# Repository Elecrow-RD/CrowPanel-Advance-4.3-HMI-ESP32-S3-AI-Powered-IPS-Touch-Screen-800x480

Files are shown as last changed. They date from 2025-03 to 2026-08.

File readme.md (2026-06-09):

## Menu
### 1, Product picture
### 2, Product version number
### 3, product information
### 4, Use the driver module
### 5,Quick Start
### 6,Folder structure.
### 7,Pin definition
### 8,Guidelines for downloading some of the files from the github repository

### 1, Product picture

Crowpanel Advance 4.3 HMI display support Meshtastic

### 2, Product version number

| | Hardware | Software | Remark |
| ---- | --- | --- | --- |
| 1 | V1.0 | V1.0 | old |
| 2 | V1.1 | V1.1 | old |
| 3 | V1.2 | V1.2 | old |
| 4 | V1.3 | V1.2 | latest |

### Version update points:
① Version 1.1 updated the control of backlight on the basis of the original, the backlight of version 1.2 is controlled by STC8H1K28 microcontroller, and the backlight is lit in the program by sending the value to this microcontroller address (0x30). The values are 0-245, where 245 switches off the backlight and 0 is the maximum brightness.

② Version 1.1 has a new option for function switching, see above for details. When using the case, please select the corresponding program to test or modify according to the version number of your motherboard.

## Version 1.2
Only the button component has been updated. All other hardware and I/O pins remain the same as in the previous version.

## Version 1.3
Version 1.3 is simply an update to the previous version that modifies the packaging of the touchscreen FPC connector. There are no other differences.

### 3, product information

| Main Chip-ESP32-S3-WROOM-1-N16R8 | |
| --- | --- |
| CPU/SoC | high-performance Xtensa 32-bit LX7 dual-core processor, with up to 240MHz |
| System Memory | 512KB SRAM、8M PSRAM |
| Memory | 16M Flash，384KB ROM |
| Development Language | MicroPython、C/C++ |
| Development Environment | ESP-IDF、Arduino IDE、PlatformIO、MicroPython |
| **Screen** | |
| Size | 4.3 inch |
| Diver IC | ST7265 |
| Resolution | 800*480 |
| Display Panel | IPS Panel |
| Touch Panel | Capacitive Single Touch |
| Viewing Angle | 178° |
| Brightness | 400 cd/m²(Typ.) |
| Color Depth | 16-bit |
| **Wireless Communication - Onboard Antenna** | |
| WiFi | Support 2.4GHz, 802.11a/b/g/n |
| Bluetooth | Support Bluetooth 5.0 and BLE |
| Other | **LoRa** |
| **Interface/Function** | |
| Interface | USB port, UART, I2C, SD card slot, battery socket, speaker port, microphone, etc. |
| Function | RTC clock, audio amplifier, volume control, battery charge management, USB to UART, etc. |
| **Button/LED Indicator** | |
| Reset Button | Yes, press to reset the device |
| Boot Button | Yes, press and hold the power button to burn the program |
| PWR | Power indicator |
| CHG | Lithium battery charging status, completion indication |
| **Other** | |
| Installation method | Back hanging, fixed hole |
| Operating temperature | -20~70 °C |
| Storage temperature | -30~80 °C |
| Power Input | 5V/2A, USB or UART terminal |
| Active Area | 95.5mm*54mm |
| Dimensions | 121.9*75.6*15.3mm |

### 4, Use the driver module

| Name | dependency library |
| --- | --- |
| LVGL | lvgl/lvgl@8.3.3 |
| ST7789 | Adafruit GFX Library<br/>version=1.11.0 |

### 5,Quick Start
### Arduino IDE starts

#### Teaching Case Path：./example/example_code4.3

1.Download the library files used by this product to the 'libraries' folder.

C:\Users\Documents\Arduino\libraries\



2.Open the Arduino IDE



3.Open the code configuration environment and burn it



### ESP-IDF starts

#### Teaching Case Path：./example/idf_code

1.Right-click on an empty space in the project folder and select "Open with VS Code" to open the project.


2.In the IDF plug-in, select the port, then compile and flash


### 6,Folder structure.
|--3D file： Contains 3D model files (.stp) for the hardware. These files can be used for visualization, enclosure design, or integration into CAD software.

|--Datasheet: Includes datasheets for components used in the project, providing detailed specifications, electrical characteristics, and pin configurations.

|--Eagle_SCH&PCB: Contains Eagle CAD schematic (.sch) and PCB layout (.brd) files. These are used for circuit design and PCB manufacturing.

|--example: Provides example code and projects to demonstrate how to use the hardware and libraries. These examples help users get started quickly.

|--factory_firmware: Stores pre-compiled factory firmware that can be directly flashed onto the device. This ensures the device runs the default functionality.

|--factory_sourcecode: Contains the source code for the factory firmware, allowing users to modify and rebuild the firmware as needed.

|--libraries: Includes necessary libraries required for compiling and running the project. These libraries provide drivers and additional functionalities for the hardware.

|--Squareline_studio Instructions for use: Squareline_studio instructions: Demonstrate the use of squareline studio.

### 7,Pin definition

#define HSPI_MISO  4

#define HSPI_MOSI  6

#define HSPI_SCLK  5

#define HSPI_SS    19

#define SD_MOSI 6

#define SD_MISO 4

#define SD_SCK 5

#define SD_CS 0 //The chip selector pin is not connected to IO

#define I2S_DOUT 4

#define I2S_BCLK 5

#define I2S_LRC 6

      cfg.pin_d0 = GPIO_NUM_21;    // B0

      cfg.pin_d1 = GPIO_NUM_47;    // B1

      cfg.pin_d2 = GPIO_NUM_48;   // B2

      cfg.pin_d3 = GPIO_NUM_45;    // B3

      cfg.pin_d4 = GPIO_NUM_38;    // B4

      cfg.pin_d5 = GPIO_NUM_9;    // G0

      cfg.pin_d6 = GPIO_NUM_10;    // G1

      cfg.pin_d7 = GPIO_NUM_11;    // G2

      cfg.pin_d8 = GPIO_NUM_12;   // G3

      cfg.pin_d9 = GPIO_NUM_13;   // G4

      cfg.pin_d10 = GPIO_NUM_14;   // G5

      cfg.pin_d11 = GPIO_NUM_7;  // R0

      cfg.pin_d12 = GPIO_NUM_17;  // R1

      cfg.pin_d13 = GPIO_NUM_18;  // R2

      cfg.pin_d14 = GPIO_NUM_3;  // R3

      cfg.pin_d15 = GPIO_NUM_46;  // R4

      cfg.pin_henable = GPIO_NUM_42;
      
      cfg.pin_vsync = GPIO_NUM_41;
      
      cfg.pin_hsync = GPIO_NUM_40;
      
      cfg.pin_pclk = GPIO_NUM_39;

#define TOUCH_GT911_SCL 16

#define TOUCH_GT911_SDA 15

### 8,Guidelines for downloading some of the files from the github repository

##### 1, open the link in your browser: https://downgit.github.io/

##### 2, paste the URL of the GitHub destination folder in the input box (example format: `https://github.com/username/repository name/tree/branch name/folder path`)

github_download1

##### 3, even a that way to download the file.

①Click the “Create Download Link” button to create a download link, copy the link and open it with your browser to download the contents of the corresponding folder directly.

github_download2

②Click Download, and you can also download it directly.

github_download3

#### Note: DownGit downloads are stored by default in **your browser's default downloads folder**, usually:

- **Windows**: `C:\Users\your username\Downloads\` (downloads folder)
- **macOS**: `~/Downloads/` (downloads folder)
- **Linux**: `~/Downloads/` (Downloads folder)

If you change the default download path in your browser, the file will be stored in the download location you set. You can find the downloaded file path in your browser's **Download History** (shortcut `Ctrl + J` or `Cmd + J`).

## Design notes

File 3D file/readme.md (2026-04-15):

**The 3D drawings in the “advance-hmi4_3-20260116” file are the latest 3D files for version 1.2. The buttons are shorter, and there are minor changes to the housing.**

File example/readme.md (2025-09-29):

## Arduino platform requirements for ESP32 version and library version
Board Version
esp32 by Espressif System 3.0.2
After completing the Esp32 download, replace the files in that directory；
Open the "ESP32S3_120M"(https://drive.google.com/drive/u/1/folders/1npWkVzctd7e0Y6H5hahk8uxGhy9idxCz) file we provided, copy a copy of the file from that folder to the following path in ESP32, and replace it；
(C：\Users\14175\AppData\Local\Arduino15\packages\esp32\tools\esp32-arduino-libs\idf-release_v5.1-bd2b9390ef)



Note: "ESP32S3_120M" is a recompiled official file that has enabled PSRAM high-speed communication mode, and the improved refresh rate is just one of its optimizations. If not replaced, the maximum can only reach 80M, and after replacement, the maximum is 120M.
Lib Related Versions
Ivgl: 8.3.3
LovyanGFX: 1.1.16
Adafruit GFX Library ：1.11.0
The libs are provided directly by our wiki, just use the libs provided by the wiki.

## Note: The programs in the example_code_4.3 folder on this page are version 1.0 arduino programs.

## The program here is divided into different versions, according to the version of your product to choose the corresponding program

## **The basic tutorial case is divided into 1-11 lessons:**

1,Introduction to CrowPanel-Advance-HMI Screen

2,Introduce the screen user interface and external speakers for playing songs

3,Use LVGL library to create UI interface and light up lights

4,SD card stores images and displays them locally

5,Port Introduction

6,nRF2401 communication

7,wirelessmodule_lorawan

 8,Elementary chatbot（text-to-text）

 9,wirelessmodule_zigbee

 10,Build AI Chatbot

 11,LoRa Meshtastic

### Documentation tutorial link：

https://www.elecrow.com/pub/wiki/HMI_Display_course.html

### YouTube tutorial link:

https://www.youtube.com/playlist?list=PLwh4PlcPx2Gfrtm7TmlARyF4ccTmIy-gK

### Product purchase link:

https://www.elecrow.com/crowpanel-advance-4-3-hmi-esp32-800x480-ai-display-ips-touch-artificial-intelligent-screen.html

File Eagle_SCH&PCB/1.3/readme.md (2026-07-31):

# 4.3-inch CrowPanel Advance HMI Product Hardware Driver Guide

| Item | Details |
|---|---|
| Document Version | V1.0 |
| Date | 2026-07-30 |
| Author | Codex (compiled from the project schematics and verified example code) |
| Applicable Hardware | ESP32 Display 4.3 inch V1.3 / ESP32-S3-N16R8 |
| Schematic Baseline | `1.3/ESP32 Display 4.3 inch V1.3.sch`, `1.3/ESP32-Display-4.3-inch-V1.3.pdf` |
| Software Baseline | Arduino-ESP32 3.3.8; LovyanGFX 1.2.25; LVGL 9.1.0 |

> **Authority rule:** This document uses the actual configurations from successfully tested examples in the repository as the driver baseline and verifies electrical connections against the Eagle V1.3 schematic netlist. If the two conflict, the code values take precedence, and the discrepancy is recorded under “Differences and Risks.” Capabilities without supporting code evidence are marked as “schematic-confirmed/requires hardware verification” and must not be considered verified.

## 1. Summary of Conclusions

- The main controller is an ESP32-S3-WROOM-1-N16R8 (16 MB Flash, 8 MB PSRAM), and the Arduino examples use ESP32 core 3.3.8.
- The display has an 800×480 resolution, RGB565 pixel format, and a 16-bit parallel RGB interface. The stable code baseline uses a 16 MHz pixel clock; the repository also contains examples using 18 MHz and 21 MHz.
- According to the code, the touch controller is a GT911 with I2C address `0x5D`, SDA/SCL on GPIO15/GPIO16, and a 400 kHz bus speed. The code uses polling rather than interrupts.
- According to the code, the onboard STC8 auxiliary MCU uses I2C address `0x30` and handles board-level control of the backlight, touch recovery, speaker, and other functions. Its firmware protocol is not included; only a few verified commands are available.
- GPIO4/5/6 and GPIO19/20 are multiplexed through CH486F devices and DIP switches. SD, I2S audio, wireless SPI, digital microphone, and UART/Zigbee cannot all be enabled simultaneously without restrictions.
- DHT20, nRF24L01, SX1262, and Zigbee are external example devices connected through expansion ports; they are not onboard devices in the V1.3 schematic.

## 2. Evidence Levels and Porting Principles

| Level | Definition | Usage Principle |
|---|---|---|
| A - Code-verified | A complete initialization and execution path exists in the repository's product examples | Preferred values for porting |
| B - Schematic-confirmed | Explicitly present in the V1.3 schematic but not directly driven by the ESP32 examples | May be used for development, but hardware testing must be added |
| C - External example | Example code has been run with the device connected externally through an expansion port | Valid only when the corresponding module is connected and the DIP switches are set to the appropriate mode |
| D - Inferred | Inferred from device functionality or net relationships, without protocol documentation or actual testing | Must not be presented as a production-ready capability |

When porting, select a GPIO multiplexing scenario before initializing peripherals. Do not simply combine all examples. The display and I2C bus may be treated as persistent infrastructure; functions associated with GPIO4/5/6 and GPIO19/20 must be enabled mutually exclusively according to the product scenario.

## 3. Peripheral Overview

| Category | Device/Interface | Connection and Driver | Status |
|---|---|---|---|
| Main controller | ESP32-S3-WROOM-1-N16R8 | Arduino HAL; Wi-Fi; GPIO Matrix; PSRAM | A |
| Display | 4.3-inch 800×480 IPS | 16-bit RGB565, GPIO3/7/9-14/17/18/21/38/45-48, PCLK 39, DE 42, HSYNC 40, VSYNC 41 | A |
| Touch | GT911 (identified by code) | I2C0, SDA 15, SCL 16, `0x5D`, 400 kHz, polling | A |
| Board-control MCU | STC8H1K28 | Shares I2C 15/16 with the ESP32; accessed at `0x30` by the code | A (incomplete protocol) |
| RTC | PCF8563-compatible device + CR1220 | I2C 15/16, 32.768 kHz crystal | B |
| Storage | MicroSD card socket | SPI: MOSI 6, MISO 4, SCK 5; CS not connected to the main controller | A |
| Audio output | NS4168 + right-channel connector | I2S: DOUT 4, BCLK 5, LRCLK 6; board-control command 248 enables the speaker | A |
| Audio input | LMD3526B261 digital microphone | CLK 19, DATA 20; I2S/PDM characteristics require additional testing against the device documentation | B |
| Wireless expansion | J9/J11/J12 | SPI 4/5/6; control pins 8/19/20/2; 3.3 V/optional 5 V | A/C |
| nRF24L01 | External module | SPI 4/5/6, CSN 19, CE 20 | C |
| SX1262 LoRa | External module | SPI 4/5/6, NSS 8, DIO1 20, RESET 19, BUSY 2 | C |
| Zigbee/UART | External module | UART1 RX 19, TX 20, 115200 8N1 | C |
| Temperature and humidity | External DHT20 | I2C 15/16, address `0x38` | C |
| USB-UART | CH340K + automatic download circuit | USB-C D+/D-; connected to ESP32 UART0, EN, and IO0 | B (programming path implicitly used) |
| Expansion interfaces | J2/J10/J13/J14 | UART0, STC UART, I2C, power | B |
| Power management | TP4059, RY3420, MT9201, MOSFET power gating | USB/external 5 V/Li-ion battery input; 3.3 V and backlight boost | B |
| Actuator | Passive buzzer B2 | Driven by STC P2.7 through an NPN transistor | B |
| Indicators/keys | BOOT, RESET, charging/power LEDs, K1 DIP switch | IO0, EN; status LEDs managed by the STC; K1 selects multiplexed channels | B |

## 4. Authoritative GPIO Assignment Table

| ESP32 GPIO | Actual Usage in Code | Schematic Connection | Driver Characteristics/Notes |
|---:|---|---|---|
| 0 | Virtual CS in SD examples; BOOT | BOOT button, not connected to SD CS | Bootstrapping pin; do not connect an external strong pull-down. The CS parameter used for SD does not represent a physical chip-select signal |
| 1 | Driven low for 120 ms during touch recovery, then changed to input | `TP_INT`, connected to the touch FPC INT pin | **Code-precedence discrepancy**; normally an input/polled during operation and briefly driven low in push-pull mode during recovery |
| 2 | SX1262 BUSY; wireless-port BUSY | J11 pin 5 | Input; used when a LoRa module is connected |
| 3 | RGB R3 | LCD R6 (fourth active red bit of the panel) | RGB peripheral output; related to bootstrapping, so avoid external conflicting levels |
| 4 | SD MISO / nRF24 MISO / SX1262 MISO / I2S DOUT | Multiplexed by U11 to SD, wireless, or the amplifier | Direction varies by mode; concurrent contention is strictly prohibited |
| 5 | SD/wireless SCK / I2S BCLK | Multiplexed by U11 | SPI/I2S clock output; concurrent use is strictly prohibited |
| 6 | SD/wireless MOSI / I2S LRCLK | Multiplexed by U11 | Output; concurrent use is strictly prohibited |
| 7 | RGB R0 (code comment) | LCD R3 | RGB output |
| 8 | SX1262 NSS / wireless CS | J11 pin 6 | SPI chip-select output, idle high |
| 9-14 | RGB G0-G5 (code comments) | LCD G2-G7 | RGB outputs |
| 15 | I2C SDA | Touch, RTC, STC, J11/J13 | Open-drain bidirectional; schematic shows a 4.7 kΩ pull-up to 3.3 V |
| 16 | I2C SCL | Touch, RTC, STC, J11/J13 | Open-drain output; schematic shows a 4.7 kΩ pull-up to 3.3 V |
| 17,18 | RGB R1,R2 (code comments) | LCD R4,R5 | RGB outputs |
| 19 | nRF24 CSN / SX1262 RESET / UART1 RX / MIC CLK | Multiplexed by U9; J12 pin 1 | Direction varies by mode; some code only sets it to OUTPUT without writing a level |
| 20 | nRF24 CE / SX1262 DIO1 / UART1 TX / MIC DATA | Multiplexed by U9; J12 pin 2 | Direction varies by mode; must match the DIP-switch position |
| 21 | RGB B0 (code comment) | LCD B3 | RGB output |
| 38 | RGB B4 (code comment) | LCD B7 | RGB output |
| 39 | RGB PCLK | LCD CLK, through 0 Ω | Recommended baseline: 16 MHz; repository examples also use 18/21 MHz |
| 40 | RGB HSYNC | LCD HSYNC | Active low |
| 41 | RGB VSYNC | LCD VSYNC | Active low |
| 42 | RGB DE | LCD DE | Data-enable output |
| 45,46 | RGB B3/R4 (code comments) | LCD B6/R7 | Related to bootstrapping; outputs while the display is running |
| 47,48 | RGB B1/B2 (code comments) | LCD B4/B5 | RGB outputs |
| RXD0/TXD0 | UART0 | CH340K, J2; connected to J10 through level isolation | Debug/programming UART; example baud rates are 9600 or 115200 |

> The LovyanGFX `pin_d0...pin_d15` comments use compressed RGB565 bit ordering, while the schematic net names use the panel's native R3-R7, G2-G7, and B3-B7 bit names. They are logically consistent and do not indicate a wiring conflict.

## 5. GPIO Multiplexing Modes

U11 multiplexes GPIO4/5/6, and U9 multiplexes GPIO19/20; K1 provides `SEL1/SEL0`. The schematic explicitly specifies only that UART1 output requires `S1=0, S0=1`. Other positions must be confirmed against the silkscreen or through hardware continuity testing and cannot be selected through software alone.

| Scenario | GPIO4 | GPIO5 | GPIO6 | GPIO19 | GPIO20 | Other |
|---|---|---|---|---|---|---|
| MicroSD | MISO | SCK | MOSI | Unused/must not conflict | Unused/must not conflict | SD CS is not physically connected |
| I2S speaker | SDATA | BCLK | LRCLK | Unused | Unused | Write 248 to `0x30` first |
| nRF24L01 | MISO | SCK | MOSI | CSN | CE | 250 kbps, channel 50 |
| SX1262 | MISO | SCK | MOSI | RESET | DIO1 | NSS 8, BUSY 2 |
| Zigbee UART | Unused | Unused | Unused | UART1 RX | UART1 TX | 115200 8N1; schematic requires S1=0, S0=1 |
| Onboard digital MIC | Unused | Unused | Unused | CLK | DATA | No capture example in the repository; format remains to be confirmed |

## 6. Detailed Driver Guide

### 6.1 ESP32-S3 Main Controller and Boot/Programming

**Hardware.** U5 is an ESP32-S3-WROOM-1, with N16R8 indicated in the schematic title. EN is active high; K4 pulls EN low to reset. K3 pulls GPIO0 low to enter download mode during reset. The CH340K automatically controls EN/IO0 through DTR/RTS and the UMH3NTN, while USB-C J1 also supplies power.

**Software layer.** Arduino-ESP32 3.3.8, using the underlying ESP-IDF HAL/drivers. Display buffers use PSRAM, while the LVGL partial double buffers are explicitly allocated in internal RAM.

```cpp
Serial.begin(115200);
// BOOT: GPIO0 low during reset; RESET: EN low.
```

**Caution.** GPIO0, 3, 45, and 46 are associated with ESP32-S3 bootstrapping. Peripherals must not force incorrect levels during power-up. The Flash/PSRAM settings for the N16R8 must match the board configuration in the Arduino IDE.

### 6.2 RGB LCD

**Interface and timing.** 800×480, RGB565, 16-bit parallel, using LovyanGFX `Bus_RGB` + `Panel_RGB`. The code mapping is as follows:

```cpp
// D0..D15
21, 47, 48, 45, 38, 9, 10, 11, 12, 13, 14, 7, 17, 18, 3, 46
// DE, VSYNC, HSYNC, PCLK
42, 41, 40, 39
```

Recommended baseline parameters:

| Parameter | Value |
|---|---:|
| Resolution/memory dimensions | 800×480 |
| Pixel format | RGB565 |
| PCLK | 16 MHz (recommended conservative value) |
| HSYNC polarity/front porch/pulse width/back porch | Active low / 8 / 4 / 8 |
| VSYNC polarity/front porch/pulse width/back porch | Active low / 8 / 4 / 8 |
| PCLK idle | High |
| Framebuffer | PSRAM |

The repository's SD examples also use 18 MHz and 21 MHz. Start porting at 16 MHz; after increasing the frequency, check for display corruption, jitter, temperature-related drift, and long-duration DMA refresh stability.

**Initialization.** After board-control I2C is ready and the backlight command has been written, call `gfx.init()` and `gfx.initDMA()`. The LVGL 9.1.0 example uses 40-line RGB565 double buffers: each buffer is `800×40×2 = 64,000` bytes and is allocated in internal RAM.

**Backlight.** The LED boost circuit is controlled by the MT9201 and STC8 rather than direct ESP32 PWM. The code writes `0` to `0x30` for maximum brightness and `245` to turn the backlight off, suggesting that `0..245` is an inverted brightness scale. No complete protocol or fade timing was found.

### 6.3 GT911 Capacitive Touch

**Code baseline.** LovyanGFX `Touch_GT911`, I2C0: SDA GPIO15, SCL GPIO16, 400 kHz, address `0x5D`, ranges 0..800/0..480, and `offset_rotation=0`. The code sets `pin_int=-1` and `pin_rst=-1` and uses polling.

```cpp
cfg.pin_sda = GPIO_NUM_15;
cfg.pin_scl = GPIO_NUM_16;
cfg.freq = 400000;
cfg.i2c_addr = 0x5D;
```

**Recovery sequence.** If `0x30` or `0x5D` does not respond, the code first writes 250 to `0x30`, then configures GPIO1 as a push-pull output and drives it low for 120 ms. It then restores GPIO1 to input mode, waits 100 ms, and retries.

**Discrepancy.** In the schematic, the GPIO1 net is named `TP_INT`, while touch reset `TP_RST` is connected to STC8 P1.7 rather than the ESP32. However, the code uses a low pulse on GPIO1 to recover touch operation. The code behavior must be preserved during maintenance; do not configure GPIO1 permanently as an interrupt-only input based solely on the net name. The board-level electrical mechanism behind this recovery procedure requires oscilloscope verification.

### 6.4 STC8 Board-Control MCU (I2C Address 0x30)

**Connection.** U13, an STC8H1K28, shares the GPIO15/16 I2C bus with the ESP32; the bus also connects to the touch controller, RTC, and expansion ports. The STC directly controls LCD backlight power/enable, the buzzer, charging-status indicators, touch reset, audio-amplifier power, and its own UART on J14.

**Verified commands.** The ESP32 acts as the I2C controller and writes one byte to the 7-bit address `0x30`:

| Command | Meaning in Code Comments | Evidence |
|---:|---|---|
| 0 | Maximum backlight brightness | Multiple LCD/SD/RF24 examples |
| 245 | Backlight off | Code comment; no independent call found |
| 248 | Turn on speaker | Online audio example |
| 250 | Activate/recover touch | All board-level startup retry paths |

```cpp
Wire.beginTransmission(0x30);
Wire.write(command);
Wire.endTransmission();
```

**Risk.** The repository does not contain the STC firmware or a complete command table. Unknown commands, returned data, intermediate backlight levels, and the command to turn off the speaker must not be guessed. Some examples refer to `0x30` as an “extended IC”; the actual device in the schematic is an STC8 MCU.

### 6.5 Shared I2C Bus, RTC, and External DHT20

**Bus.** `Wire.begin(15, 16)`; the schematic shows 4.7 kΩ pull-ups from both SDA and SCL to 3.3 V. The touch code requires 400 kHz. When Arduino `Wire.begin()` does not explicitly set the frequency, it depends on the core's default value. If the entire bus is standardized at 400 kHz, regression testing must cover the STC8, RTC, and DHT20.

| Address | Device | Status |
|---:|---|---|
| `0x30` | STC8 board-control MCU | A |
| `0x38` | External DHT20 | C; library default address |
| `0x51` (common PCF8563 address) | Onboard RTC | B/D; device confirmed by schematic, not accessed by repository code, and address requires confirmation by scanning |
| `0x5D` | GT911 touch | A; the code also notes `0x14` as a possible address, but this board uses `0x5D` |

RTC U4 uses a 32.768 kHz crystal and CR1220 backup battery; INT/CLK_OUT is not connected to the ESP32. When porting the RTC, only I2C polling can be used, and tests must be added for initial power-up, retention during power loss, and the oscillator-stop flag.

The DHT20 example calls `dht20.begin()` and reads temperature and humidity once per second. The library sends `AC 33 00`, polls every 10 ms up to 10 times, and uses the default address `0x38`. The DHT20 is a peripheral connected to the J13 I2C expansion port, not an onboard sensor.

### 6.6 MicroSD

**Connection.** GPIO6 MOSI, GPIO4 MISO, GPIO5 SCK; 3.3 V supply. The `SDCS` net in the schematic connects only to the card socket and a pull-up/test network; it is not connected to an ESP32 GPIO.

**Code baseline.** The ESP32-S3 uses `SPIClass(FSPI)`; the code passes `SD_CS=0`, and the stable example uses 40 MHz:

```cpp
SPIClass SD_SPI(FSPI);
SD_SPI.begin(5, 4, 6, 0);
SD.begin(0, SD_SPI, 40000000);
```

Another similar example in the root directory uses 80 MHz, but 40 MHz is a more appropriate porting baseline. The card socket is effectively always selected in hardware and cannot share transactions with other devices on the same physical SPI branch. GPIO0 is only an API placeholder parameter, not the SD chip-select line; also avoid changing the BOOT level as a consequence.

### 6.7 I2S Audio Output and NS4168

**Connection.** GPIO5 BCLK, GPIO6 LRCLK, and GPIO4 SDATA are routed through U11 to the NS4168. The amplifier provides differential right-channel outputs `ROUT+/-` to J15. Do not connect either output directly to ground or use them as a single-ended headphone output.

**Software.** ESP32-audioI2S 3.4.7, Wi-Fi network streaming, volume range 0..21, with the example set to 20. First initialize the shared I2C bus and write 248 to the board-control MCU, then configure the audio pins and continuously call `audio.loop()`.

```cpp
sendI2CCommand(248);
audio.setPinout(5, 6, 4); // BCLK, LRCLK, DOUT
audio.setVolume(20);
```

The NS4168 CTRL/power supply is also controlled by the STC8. Audio shares GPIO4/5/6 with SD/wireless SPI; before switching, stop and deinitialize the previous bus driver.

### 6.8 Onboard Digital Microphone

MIC1 is an LMD3526B261-OFA01: powered by 3.3 V, with GPIO19 connected to CLK and GPIO20 connected to DATA; L/R is fixed to a channel through a resistor. The signals are multiplexed through U9. The repository contains no recording or I2S/PDM initialization example, so only the electrical connections are confirmed. The sampling format, clock frequency, bit width, and channel polarity must all be determined from the device documentation and verified through actual testing.

### 6.9 External nRF24L01 Module

**Connection and configuration.** SPI: SCK 5, MISO 4, MOSI 6; CSN 19, CE 20; 3.3 V supply. RF24 1.6.1, address `"00001"`, maximum PA level, 250 kbps, RF channel 50. The receiver opens pipe 0 and calls `startListening()`; the transmitter calls `openWritingPipe()` and `stopListening()`.

```cpp
SPIClass hspi(HSPI);
hspi.begin(5, 4, 6, 19);
RF24 radio(20, 19); // CE, CSN
radio.setDataRate(RF24_250KBPS);
radio.setChannel(50);
```

GPIO19 is used both as the SPI SS parameter and as the RF24 CSN, which matches the actual code behavior. When connecting an external high-power nRF24 module, add sufficient 3.3 V decoupling close to the module and verify the available capacity of the onboard regulator.

### 6.10 External SX1262 LoRa/LoRaWAN Module

**Connection.** NSS 8, DIO1 20, RESET 19, BUSY 2, SCK 5, MISO 4, MOSI 6. Uses RadioLib 7.7.1:

```cpp
SPI.begin(5, 4, 6, 8);
SX1262 radio = new Module(8, 20, 19, 2, SPI);
radio.begin();
radio.setCurrentLimit(140.0);
radio.setTCXO(3.3);
```

The LoRaWAN example supports EU868/US915, with the default node constructed using EU868 and subBand=1. It supports ABP/OTAA, ADR, data rate, transmit power, RX2 data rate, and duty-cycle control. `setTCXO(3.3)` applies only to modules with a 3.3 V TCXO and must not be copied to modules using a standard crystal. Frequency band, antenna, and regulatory parameters must be reconfigured for the sales region.

### 6.11 External Zigbee/UART Module

GPIO19 is UART1 RX, GPIO20 is UART1 TX, and the configuration is `115200, SERIAL_8N1`. The schematic explicitly requires DIP-switch settings `S1=0, S0=1` when using UART1_OUT.

```cpp
Serial1.begin(115200, SERIAL_8N1, 19, 20);
```

This mode is mutually exclusive with the onboard digital microphone and the GPIO19/20 control signals for nRF24 and SX1262. Confirm that the external module uses 3.3 V logic levels; a 5 V UART must not be connected directly to the ESP32.

### 6.12 USB-UART, UART0, and Expansion Ports

- J1 USB-C: USB 2.0 D+/D- connects to the CH340K rather than the ESP32-S3 native USB data interface; VBUS also enters the power path.
- J2: ESP32 UART0 RX, TX, 3V3, GND.
- J10: UART0 RX and TX through a level-shifting/isolation network, external 5 V input, and GND.- J13: SCL (GPIO16), SDA (GPIO15), 3V3_OUT, and GND; suitable for I2C peripherals.

- J14: STC8 TX, RX, VIN, and GND; this is not the ESP32 UART.
- J9/J11/J12: Wireless/multiplexed expansion; see the GPIO multiplexing table for specific functions.

UART0 example: lesson-01 uses 9600, while other debugging code generally uses 115200. Production firmware should standardize on 115200 and avoid continuously occupying the download/logging channel with application UART traffic.

### 6.13 Power, Charging, and Backlight Power

**Power path (confirmed by schematic).** USB-C VBUS, J10 external 5 V, and the battery input are combined into VIN through Schottky diodes/MOSFETs; the TP4059 charges a single-cell lithium battery; the RY3420 generates 3.3 V; the MT9201 provides boosted power for the LCD LEDs; and multiple P-channel MOSFETs control peripheral power. J3 is the battery connector, with VBAT on the positive terminal and the remaining pads connected to ground.

**Software boundary.** The ESP32 does not directly configure the TP4059, RY3420, or MT9201. Charging `CHG/STD`, backlight enable, and power gating are monitored or controlled by the STC8. The repository does not contain a battery-level ADC, charging-status readout, or shutdown API. These functions are therefore classified as Level B and cannot be used by the main application until the STC protocol is available.

**Safety.** Use only a single-cell lithium battery system; verify battery polarity, permitted charging current, and temperature conditions. The expansion-port `3V3_OUT` is gated by Q8 and must not be assumed to remain active whenever the board is powered. J9 `IOT_5V` connects to VIN through L3, which is marked NC. Depending on production assembly, the 5 V pin may be unpowered and must be verified by measurement.

### 6.14 Buzzer, LEDs, Buttons, and DIP Switches

- Passive buzzer B2 is driven on the low side by STC8 P2.7 through Q4, an NPN transistor, and includes a flyback/protection network. There is no direct ESP32 GPIO connection, and the repository contains no buzzer command.
- K3 BOOT: Pulls GPIO0 low when pressed. K4 RESET: Pulls ESP32_EN low when pressed.
- D14 is a hardware power indicator LED. The charging/completion states of dual-color LED D1 are controlled through the STC8 and TP4059 status path.
- The two-position K1 DIP switch generates `SEL1/SEL0` and also selects the U9/U11 signal routing. Before changing functions, power off the board or first place the relevant GPIOs in a high-impedance state.

## 7. Recommended Initialization Sequence

```text
1. Start and initialize Serial(115200)
2. Wire.begin(15,16), then wait 50 ms
3. Probe 0x30 and 0x5D
4. If probing fails: command 250 -> drive GPIO1 low for 120 ms -> set GPIO1 as input -> wait 100 ms -> retry
5. Write the backlight value (typically 0) to 0x30
6. gfx.init() -> gfx.initDMA() -> clear the display
7. Initialize LVGL/touch polling
8. Based on the DIP-switch setting and product use case, initialize only one multiplexed function group
9. For audio use cases, additionally send command 248; complete address probing for external sensors
```

Production firmware should not wait indefinitely in a loop for I2C devices. It should implement timeouts, a degraded-mode UI, and error codes. This document retains the timing from the original examples as a reference for hardware recovery.

## 8. Schematic and Code Discrepancies

| Item | Schematic/Label | Verified Code | Adopted Value and Handling |
|---|---|---|---|
| Touch GPIO1 | `TP_INT` | Driven low for 120 ms, then restored as an input | Use the recovery sequence from the code; poll during normal operation, with the root cause pending hardware confirmation |
| Touch reset | `TP_RST` connected to STC8 P1.7 | LovyanGFX `pin_rst=-1` | The ESP32 does not reset it directly; recover through board-control command 250 plus the GPIO1 sequence |
| MicroSD CS | `SDCS` not connected to the ESP32 | `SD_CS=0` | There is no physical CS; GPIO0 is an API placeholder and must not be treated as a conventional multi-device SPI chip-select |
| LCD RGB bit names | Schematic uses R3-R7/G2-G7/B3-B7 | Code comments use R0-R4/G0-G5/B0-B4 | This is a naming difference caused by compacting the active bits; use the GPIO mapping as authoritative |
| LCD PCLK | No software frequency specified in the schematic | Multiple versions use 16/18/21 MHz | Use 16 MHz as the porting baseline; higher frequencies require regression testing |
| Touch address | Hardware diagram does not explicitly specify an address | `0x5D`; code notes that `0x14` may also be possible | Use `0x5D` on this board; test `0x14` only after replacing the display or changing strap settings |
| GPIO19 initialization | Multiplexed signal in the schematic | Some display/LVGL examples set it to OUTPUT without explanation | Do not treat this as a required display step; initialize its direction according to the selected U9 mode |
| Wireless chip select | J9 pin 1 through the U9/U11 network | nRF24 uses GPIO19; SX1262 uses GPIO8 | These are two different module configurations; use the corresponding code for each and do not combine them |
| SD SPI frequency | No value specified in the schematic | 40 MHz and 80 MHz | Use 40 MHz as the conservative baseline; 80 MHz requires card-type and temperature regression testing |
| I2C frequency | Touch driver uses 400 kHz; `Wire.begin` does not explicitly set the frequency | Multiple devices share the bus | If using 400 kHz, verify the STC8, RTC, and DHT20; otherwise retain the core default |
| U13 function name | STC8H1K28 in the schematic | Referred to as “extended IC/microcontroller” in the code | Standardize the documentation on “STC8 board-control MCU”; protocol version unknown |

## 9. Risks and Precautions

1. **Multiplexing conflicts (high).** GPIO4/5/6 and GPIO19/20 may be used simultaneously by different libraries. Before combining projects, implement a single mode state machine. When switching modes, stop SPI/I2S/UART first, then change the DIP-switch/routing configuration and reinitialize the interfaces.
2. **No SD chip select (high).** The card remains connected to the bus at all times. SD mode cannot simply share the bus with wireless SPI/audio, and the card may drive MISO during power-up.
3. **3.3 V logic levels (high).** The ESP32, touch controller, SD card, and wireless/I2C expansion interfaces are all designed for 3.3 V logic. External 5 V UART/I2C/SPI devices require level shifting.
4. **Boot strapping (high).** The power-up levels on GPIO0/3/45/46 may affect boot behavior. The display and expansion modules must not strongly drive these pins during the reset sampling window.
5. **Missing board-control protocol (high).** The STC8 firmware and complete command set are not included in the repository. Before porting backlight, speaker, buzzer, power, and charging-status functions, obtain the protocol and firmware version from the hardware team/vendor.
6. **Backlight/speaker drive characteristics (medium-high).** The LCD LEDs use a boosted constant-current circuit, and the speaker uses a BTL differential output. Do not treat the backlight pin or amplifier outputs as standard GPIOs or single-ended audio.
7. **Pixel/SPI clock margin (medium).** Successful operation with the repository code does not guarantee stability across all production lots, temperatures, SD cards, and ribbon cables. Use a 16 MHz PCLK and 40 MHz SD SPI by default for production, and perform stress testing.
8. **I2C bus blocking (medium).** The board controller, touch controller, RTC, and external sensors share the same bus. Before adding devices, check for address conflicts, total pull-up resistance, trace/cable length, and clock stretching.
9. **RTC backup battery (medium).** CR1220 polarity, initial assembly voltage, and shipping requirements must be incorporated into the manufacturing process. Software must handle invalid time values and oscillator-stop conditions.
10. **Example credentials (high, software security).** The online-audio example contains plaintext Wi-Fi SSIDs/passwords. Production firmware must not reuse them; replace them and purge historically exposed credentials before delivery.
11. **LoRa regulatory compliance (high).** EU868/US915 settings, transmit power, duty cycle, and antenna must comply with regional certification requirements. The TCXO voltage must also match the module version.

## 10. Software Dependencies and Porting Checklist

| Function | Software Layer/Version | Key Entry Point |
|---|---|---|
| Basic HAL | Arduino-ESP32 3.3.8 | `Wire`, `SPIClass`, `Serial`, GPIO |
| LCD/touch | LovyanGFX 1.2.25 | `Bus_RGB`, `Panel_RGB`, `Touch_GT911` |
| GUI | LVGL 9.1.0 | 800×480, 40-row double buffering, partial render |
| SD | Arduino ESP32 `FS`/`SD` | FSPI, 40 MHz, no physical CS |
| Network audio | ESP32-audioI2S 3.4.7 | GPIO 5/6/4, continuous `audio.loop()` |
| nRF24 | RF24 1.6.1 | Custom HSPI, CE 20/CSN 19 |
| LoRaWAN | RadioLib 7.7.1 | SX1262 + `LoRaWANNode` |
| DHT20 | Repository `Crowbits_DHT20` | Wire, address 0x38 |

When porting to ESP-IDF, the corresponding layers are `esp_lcd_rgb_panel`, `esp_lcd_touch_gt911` (or a custom GT911 driver), I2C master, SPI master/SDSPI, I2S STD/PDM, UART, and GPIO. The board-control MCU startup commands and multiplexing constraints must be preserved.

## 11. Maintenance Acceptance Checklist

- [ ] Flashing, BOOT, RESET, and serial logging operate correctly.
- [ ] Both cold boot and warm reset can detect `0x30` and `0x5D`, and the touch recovery path works.
- [ ] LCD solid-color, grayscale, checkerboard, and 24-hour DMA refresh tests complete without display corruption.
- [ ] Touch behavior is correct at all four corners, along the edges, under rotation, and with multitouch.
- [ ] SD repeatedly mounts, reads and writes large files, and recovers from power loss using the target card type.
- [ ] The selected multiplexing position matches the software mode, with no GPIO contention in other positions.
- [ ] Audio is free of pops, the BTL output is not grounded, and temperature rise at maximum volume is acceptable.
- [ ] The 3.3 V rail does not sag when the wireless module transmits at maximum power, and EMI/RF performance meets requirements.
- [ ] After all I2C peripherals are connected, there are no address conflicts or long-term bus lockups.
- [ ] USB, external 5 V, and lithium-battery power paths and charging status have all been verified.
- [ ] Example Wi-Fi credentials have been removed, and LoRa regional parameters match certification requirements.

## 12. Code and Hardware Documentation Index

- Schematic: `1.3/ESP32 Display 4.3 inch V1.3.sch`
- Schematic PDF: `1.3/ESP32-Display-4.3-inch-V1.3.pdf`
- LCD/touch/LVGL: `Arduino/lesson-03/BigInch_LVGL/`
- SD: `Arduino/lesson-04/SD_CrowPanel_ESP32_Advance_HMI_4_3_5_0_7_0/`
- I2C DHT20 expansion example: `Arduino/lesson-05/Port_CrowPanel_ESP32_Advance_HMI_4_3_5_0_7_0/`
- nRF24: `Arduino/lesson-06/READ/`, `Arduino/lesson-06/WRITE/`
- SX1262/LoRaWAN: `Arduino/lesson-07/code/sendATcommands_7.0/`
- Zigbee/UART: `Arduino/lesson-09/zigbee_7.0/`
- I2S network audio: `Arduino/lesson-02/OnlineAudio_large/`

## 13. Current Documentation Gaps

The following materials are not included in the repository and should be prioritized for future maintenance: the STC8 board-control firmware and complete I2C protocol; exact LCD panel and touchscreen part numbers/data sheets; the MT9201 backlight current design value; the TP4059 configured charging current; the digital microphone interface format; the official function table for all four DIP-switch combinations; external pinout diagrams for each expansion port; and the production hardware validation report. Once these materials are available, this document should be versioned accordingly, and Level B/D items should be updated to Level A conclusions verified through testing.

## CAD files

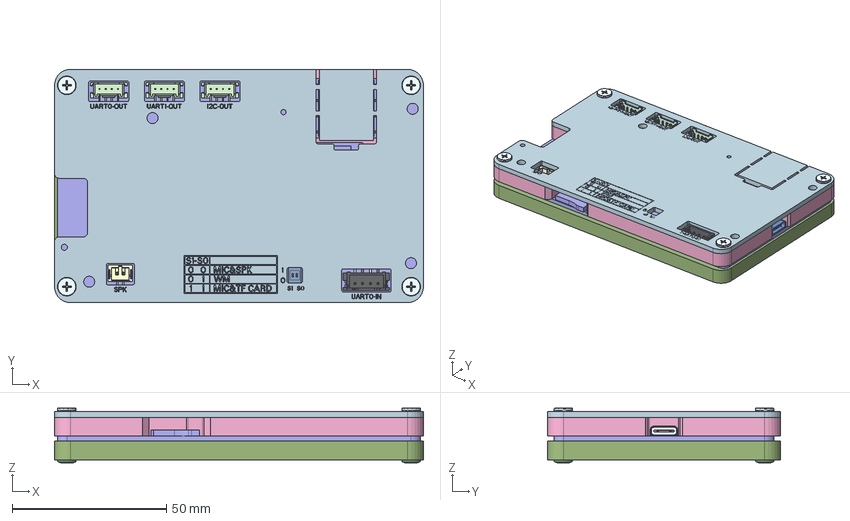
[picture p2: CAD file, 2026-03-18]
3D file/advance-hmi4_3-20260126.stp
119.5 x 75.6 x 17.7 mm
4_3-PCB-V2_17_1_1_1_1_1_1_1_1_2
BOSS-EXTRUDE7_4__1_1_4_1_1_1_1_
BOSS-EXTRUDE7_5__1_1_4_1_1_1_1_
BOSS-EXTRUDE7_8__1_1_4_1_1_1_1_
BOSS-EXTRUDE7_3__1_1_4_1_1_1_1_
BOSS-EXTRUDE7_7__1_1_4_1_1_1_1_
BOSS-EXTRUDE14_4__1_1_4_1_1_1_1
BOSS-EXTRUDE14_2__1_1_4_1_1_1_1
BOSS-EXTRUDE14_8__1_1_4_1_1_1_1
BOSS-EXTRUDE14_5__1_1_4_1_1_1_1
BOSS-EXTRUDE7_6__1_1_4_1_1_1_1_
CUT-EXTRUDE5_1_1_4_1_1_1_1_1_1_
MIRROR2_1_1_4_1_1_1_1_1_1_1_1_2
BOSS-EXTRUDE7_1__1_1_4_1_1_1_1_
BOSS-EXTRUDE14_10__1_1_4_1_1_1_
BOSS-EXTRUDE14_11__1_1_4_1_1_1_
BOSS-EXTRUDE14_9__1_1_4_1_1_1_1
BOSS-EXTRUDE14_6__1_1_4_1_1_1_1
BOSS-EXTRUDE14_12__1_1_4_1_1_1_
BOSS-EXTRUDE14_3__1_1_4_1_1_1_1
BOSS-EXTRUDE14_7__1_1_4_1_1_1_1
BOSS-EXTRUDE7_9__1_1_4_1_1_1_1_
BOSS-EXTRUDE7_2__1_1_4_1_1_1_1_
7-PIN-PAIMU_7-2_5_5_1_1_1_1_1_1 x 2
GROVE_CONNECTOR__SIT__3-2_1_4_1 x 3
SLIDE-SWITCH_3_6_1_1_1_1_1_1_1_
SLIDE-SWITCH_3_6_2_1_1_1_1_1_1_
SLIDE-SWITCH_3_6_3_1_1_1_1_1_1_
SLIDE-SWITCH_3_6_4_1_1_1_1_1_1_
SLIDE-SWITCH_3_6_5_1_1_1_1_1_1_
4_3LCD_6_1_1_1_1_1_1_1_1_2
4_3TOP_14_1_1_1_1_1_1_1_1_2
4_3MIDDLE_26_1_1_1_1_1_1_1_1_2
4_3BOTTOM_42_1_1_1_1_1_1_1_1_2
ZM_M3_12 x 4
ZM_M2_5 x 4

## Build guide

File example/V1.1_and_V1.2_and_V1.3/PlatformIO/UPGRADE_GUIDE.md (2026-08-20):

# PlatformIO + LVGL 9.1 Upgrade Guide

## Fixed toolchain

| Item | Version |
| --- | --- |
| PlatformIO Core | 6.1.19 or newer |
| pioarduino platform-espressif32 | 55.03.39 |
| Arduino-ESP32 | 3.3.9 |
| ESP-IDF libraries | 5.5.4 |
| Xtensa toolchain | 14.2.0 (2026-01-21) |
| LVGL | 9.1.0 |
| LovyanGFX | 1.2.26 |

The platform URL and every project library are pinned in `platformio.ini`.
PlatformIO resolves and downloads the official libraries; no third-party source
has been patched.

## Build

Install PlatformIO Core 6.1.19 or newer, then run from this directory:

```powershell
pio run
```

Upload and monitor commands:

```powershell
pio run --target upload
pio device monitor --baud 115200
```

On Windows, enable Win32 long-path support. The Arduino-ESP32 package contains
Matter headers whose extracted paths can exceed the legacy 260-character limit.
As a temporary alternative, set `PLATFORMIO_CORE_DIR` to a short path such as
`C:\temp\pio` before the first build.

## Runtime checks

1. Confirm that I2C devices `0x30` and `0x5D` are detected.
2. Confirm that the 800 x 480 RGB panel displays the SquareLine screen.
3. Confirm touch coordinates and both On/Off buttons.
4. Confirm GPIO 19 changes state when the buttons are released.
5. Observe several minutes of full-screen refresh for tearing or corruption.
6. Confirm that both 128,000-byte LVGL partial buffers are allocated from PSRAM.

The firmware aborts with a serial message if either display buffer cannot be
allocated. The display uses two 80-line partial buffers. The two GPIO controls
use fixed-style clickable objects instead of themed buttons, so their pressed
and released states do not redraw the single RGB framebuffer. LVGL is notified
only after an actual framebuffer write is complete.

## Generated firmware

A successful build creates:

- `.pio/build/advance-hmi/firmware.bin`
- `.pio/build/advance-hmi/firmware.factory.bin`
- `.pio/build/advance-hmi/firmware.elf`

`firmware.factory.bin` is the combined image for address `0x0`.

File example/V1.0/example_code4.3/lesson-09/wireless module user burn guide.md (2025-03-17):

## Wirless Module H2/C6 Single Board Burn-in Method

### 1.Tools to be prepared

| | Tools | quantities |
| ---- | --- | --- |
| 1 | Single Female DuPont Cable | 4 |
| 2 | Serial Module Tools | 1 |
| 3 | Wirless Module H2/C6 | 1 |
| 4 | Soldering Iron & Wire | |

 Single Female DuPont Cable
 


Wirless Module H2/C6



Serial modules (CH340/CP2102, etc. are fine)



### 2.Weld line.

The burn-in pins for the Wirless Module H2/C6 are the same, and the four wires that need to be soldered are located as follows：

（Arrow pointing up）

| RX | TX |
| ---- | ---- |
| | |
| | |
| | |
| 3V3  | |
| GND  | |
| | |

Module Pin Definition

The finished soldering is shown below.





### 3.Burning

RX is connected to TX of the serial module;

TX connection to the RX of the serial module;

3V3 connection to the 3V3 of the serial module;

GND connection to the GND of the serial module.

Connect the serial module to the computer and find the corresponding serial device number (e.g. COM7) in the Task Manager.



Open Arduino or open the corresponding serial port under any serial port tool.



Press and hold the BOOT key and then press the RST key to enter burn mode.



The serial monitor prints to enter burn-in mode.


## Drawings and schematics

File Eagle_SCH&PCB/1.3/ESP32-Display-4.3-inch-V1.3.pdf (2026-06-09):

# BOOT

# RESET

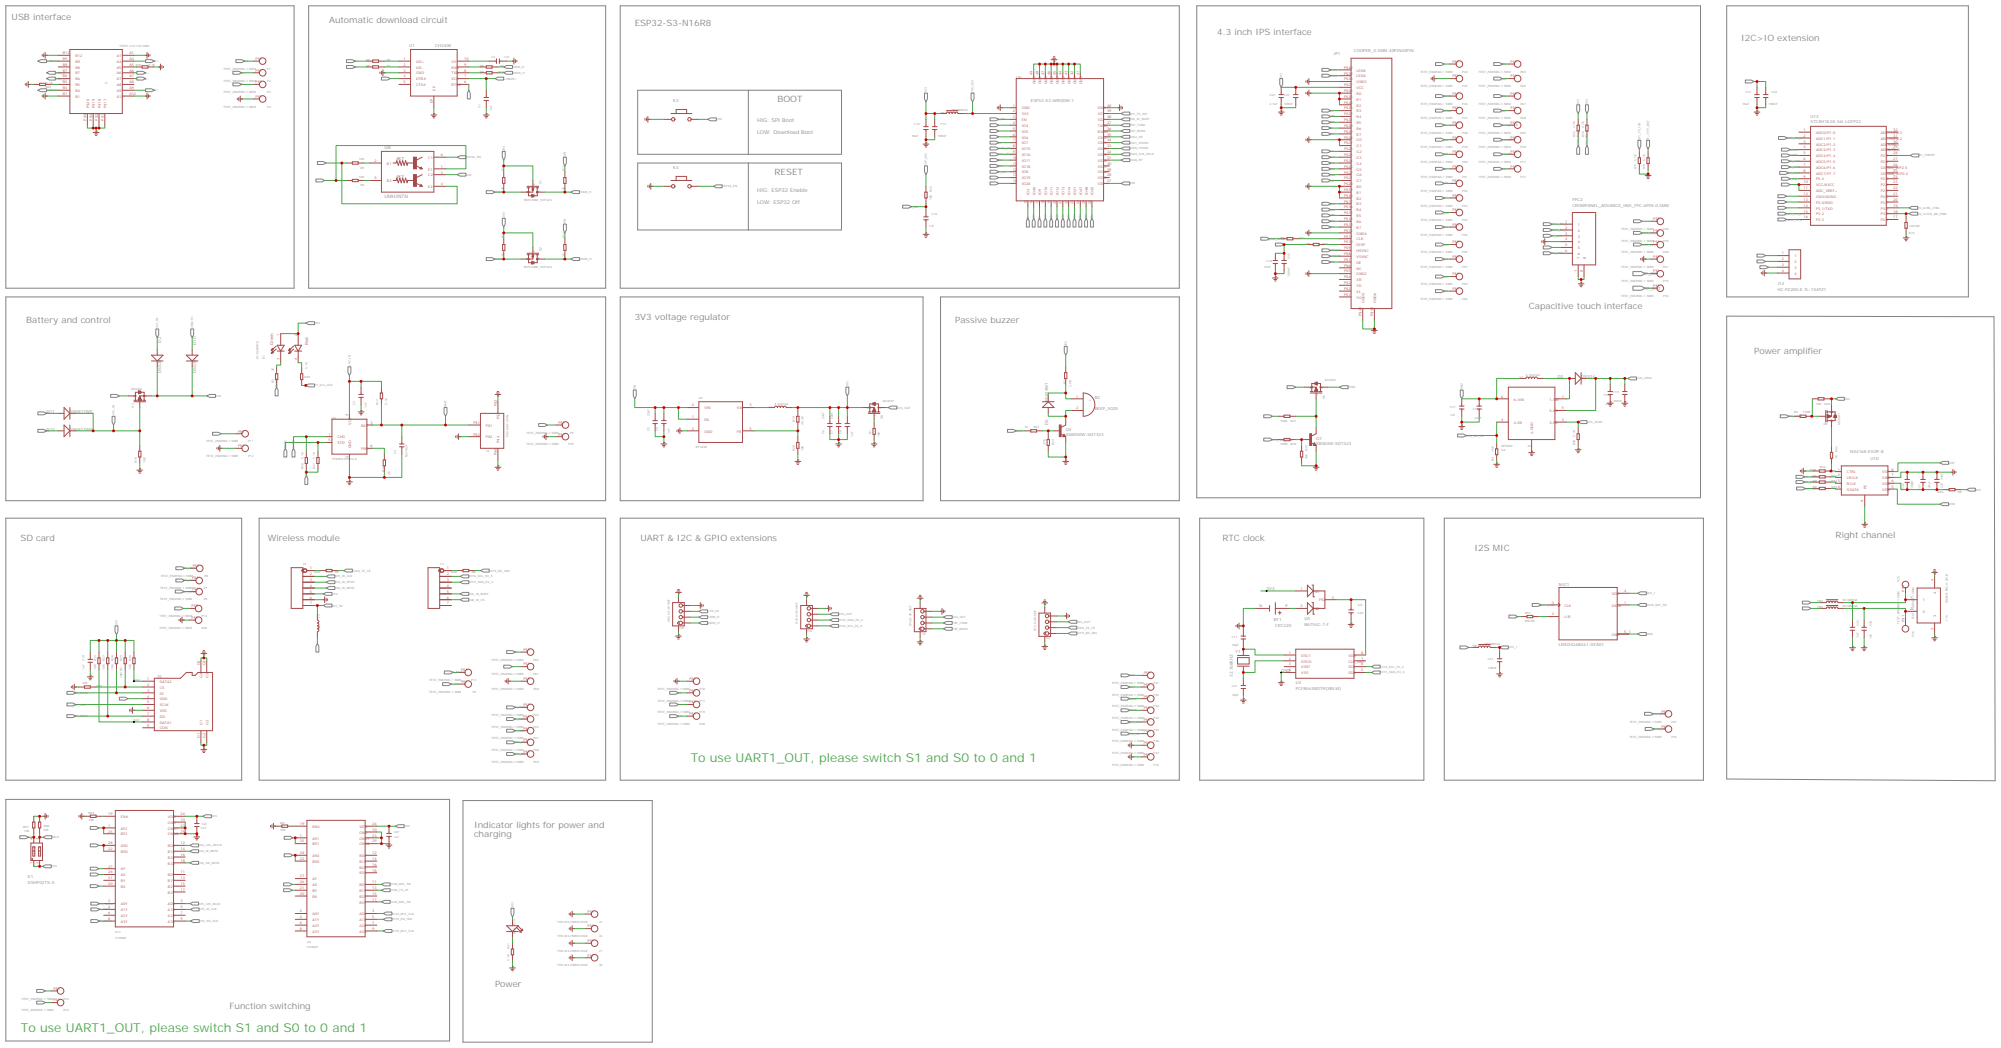
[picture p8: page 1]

To use UART1_OUT, please switch S1 and S0 to 0 and 1

Indicator lights for power and
charging

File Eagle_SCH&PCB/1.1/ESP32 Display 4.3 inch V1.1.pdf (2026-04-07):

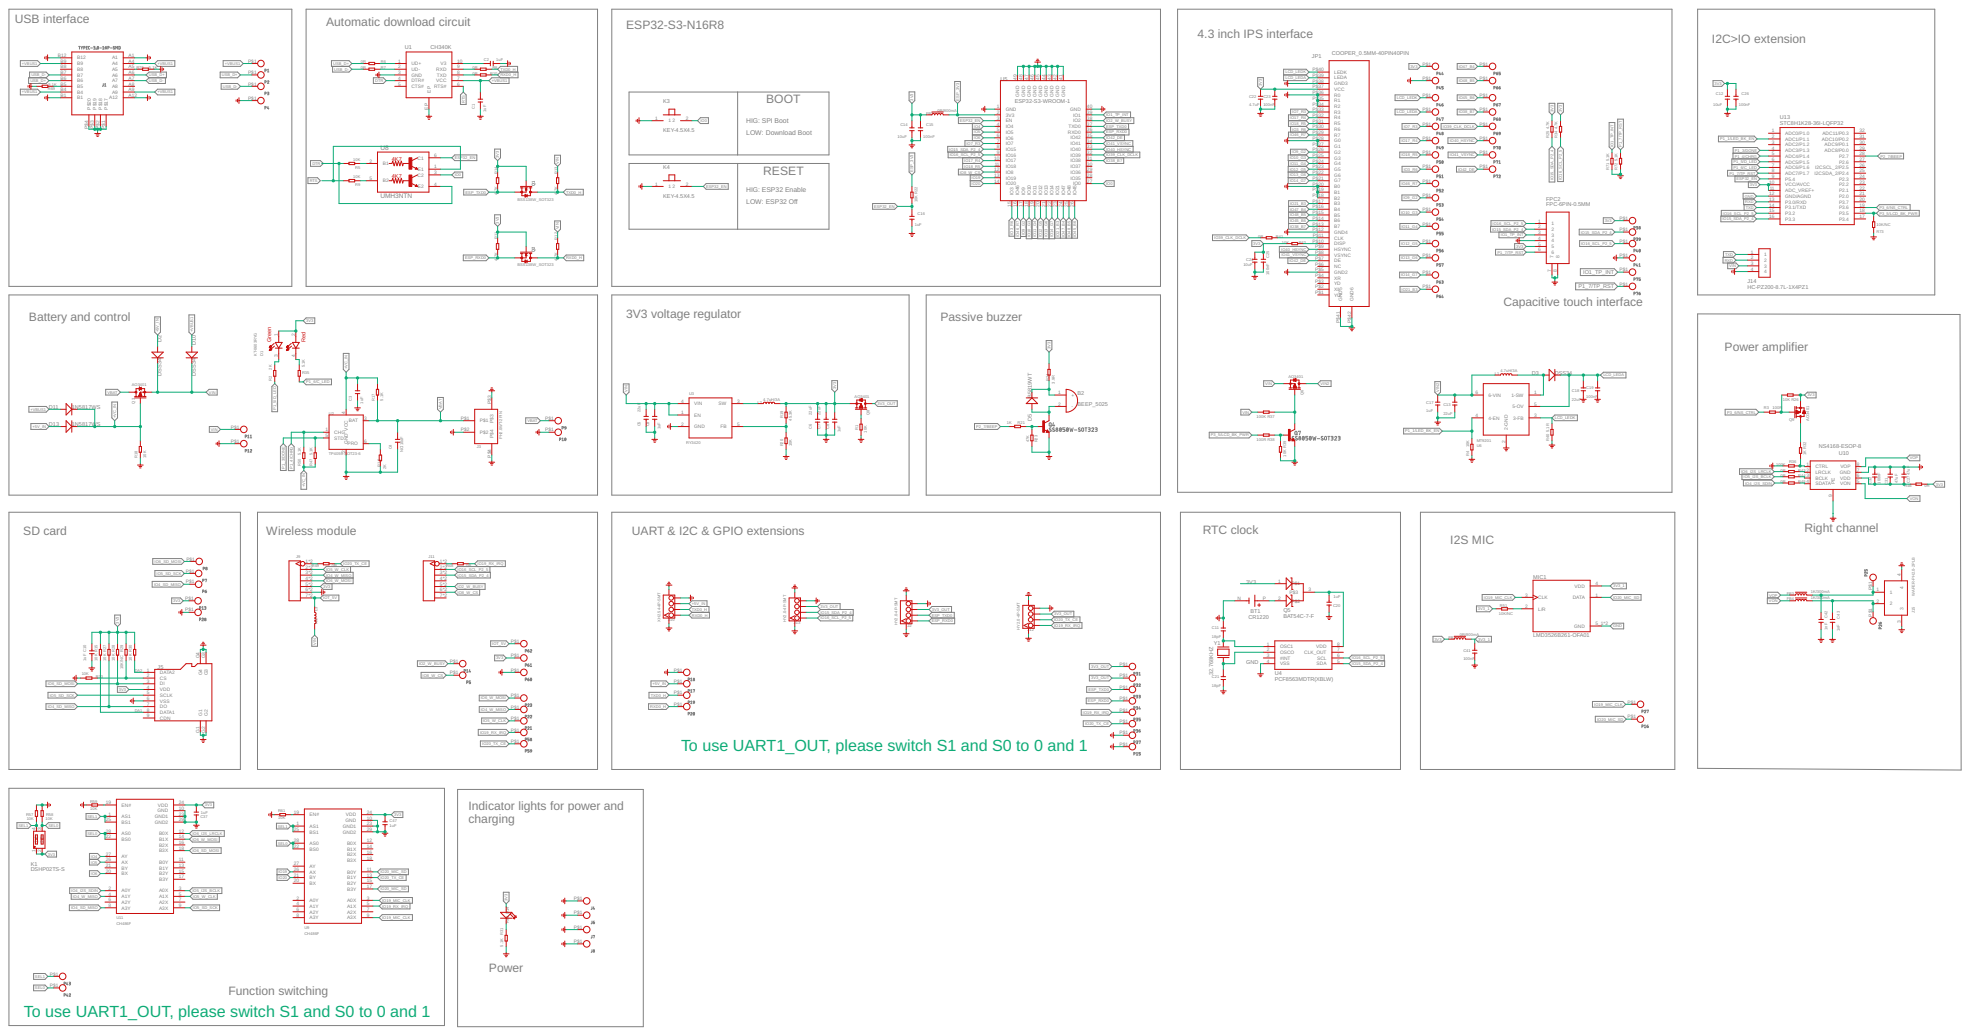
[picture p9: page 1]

HIG: SPI Boot LOW: Download Boot HIG: ESP32 Enable

To use UART1_OUT, please switch S1 and S0 to 0 and 1

Indicator lights for power and
charging

SEL0

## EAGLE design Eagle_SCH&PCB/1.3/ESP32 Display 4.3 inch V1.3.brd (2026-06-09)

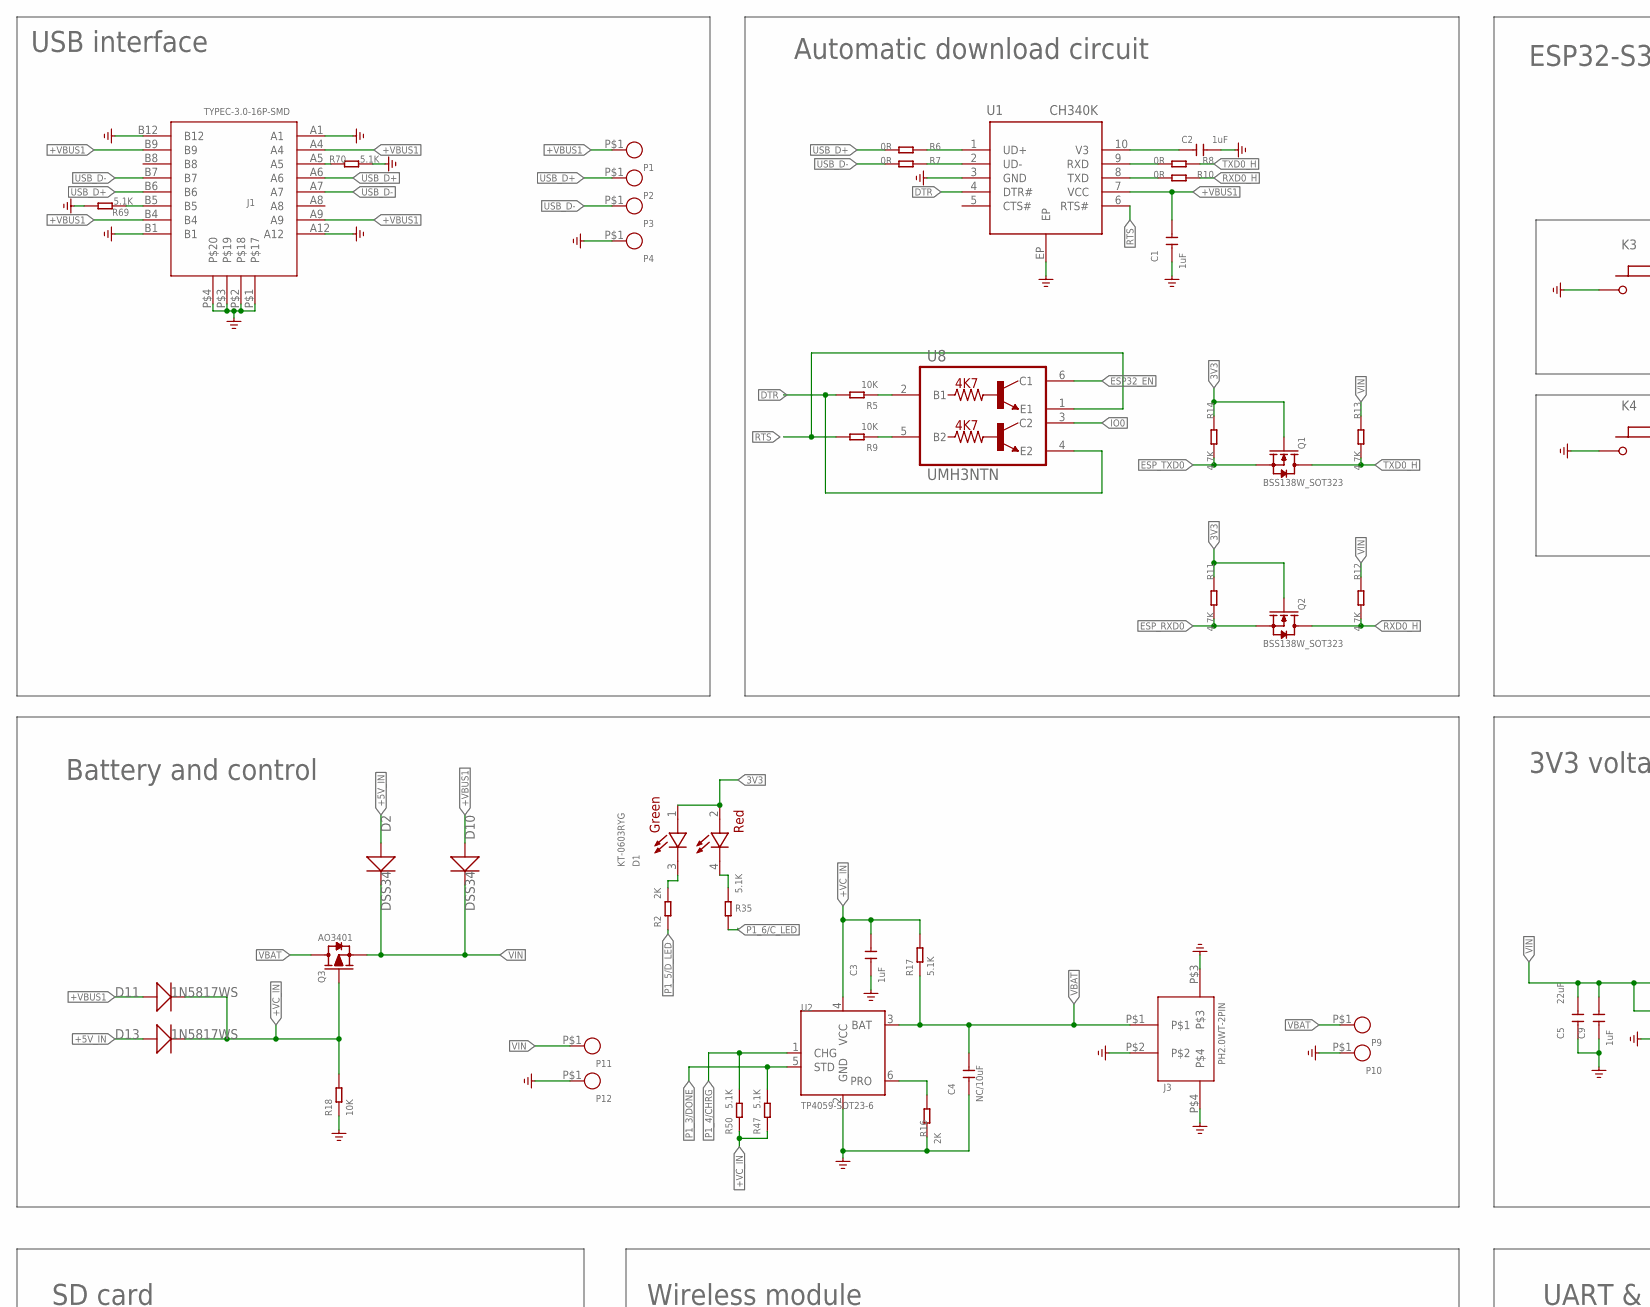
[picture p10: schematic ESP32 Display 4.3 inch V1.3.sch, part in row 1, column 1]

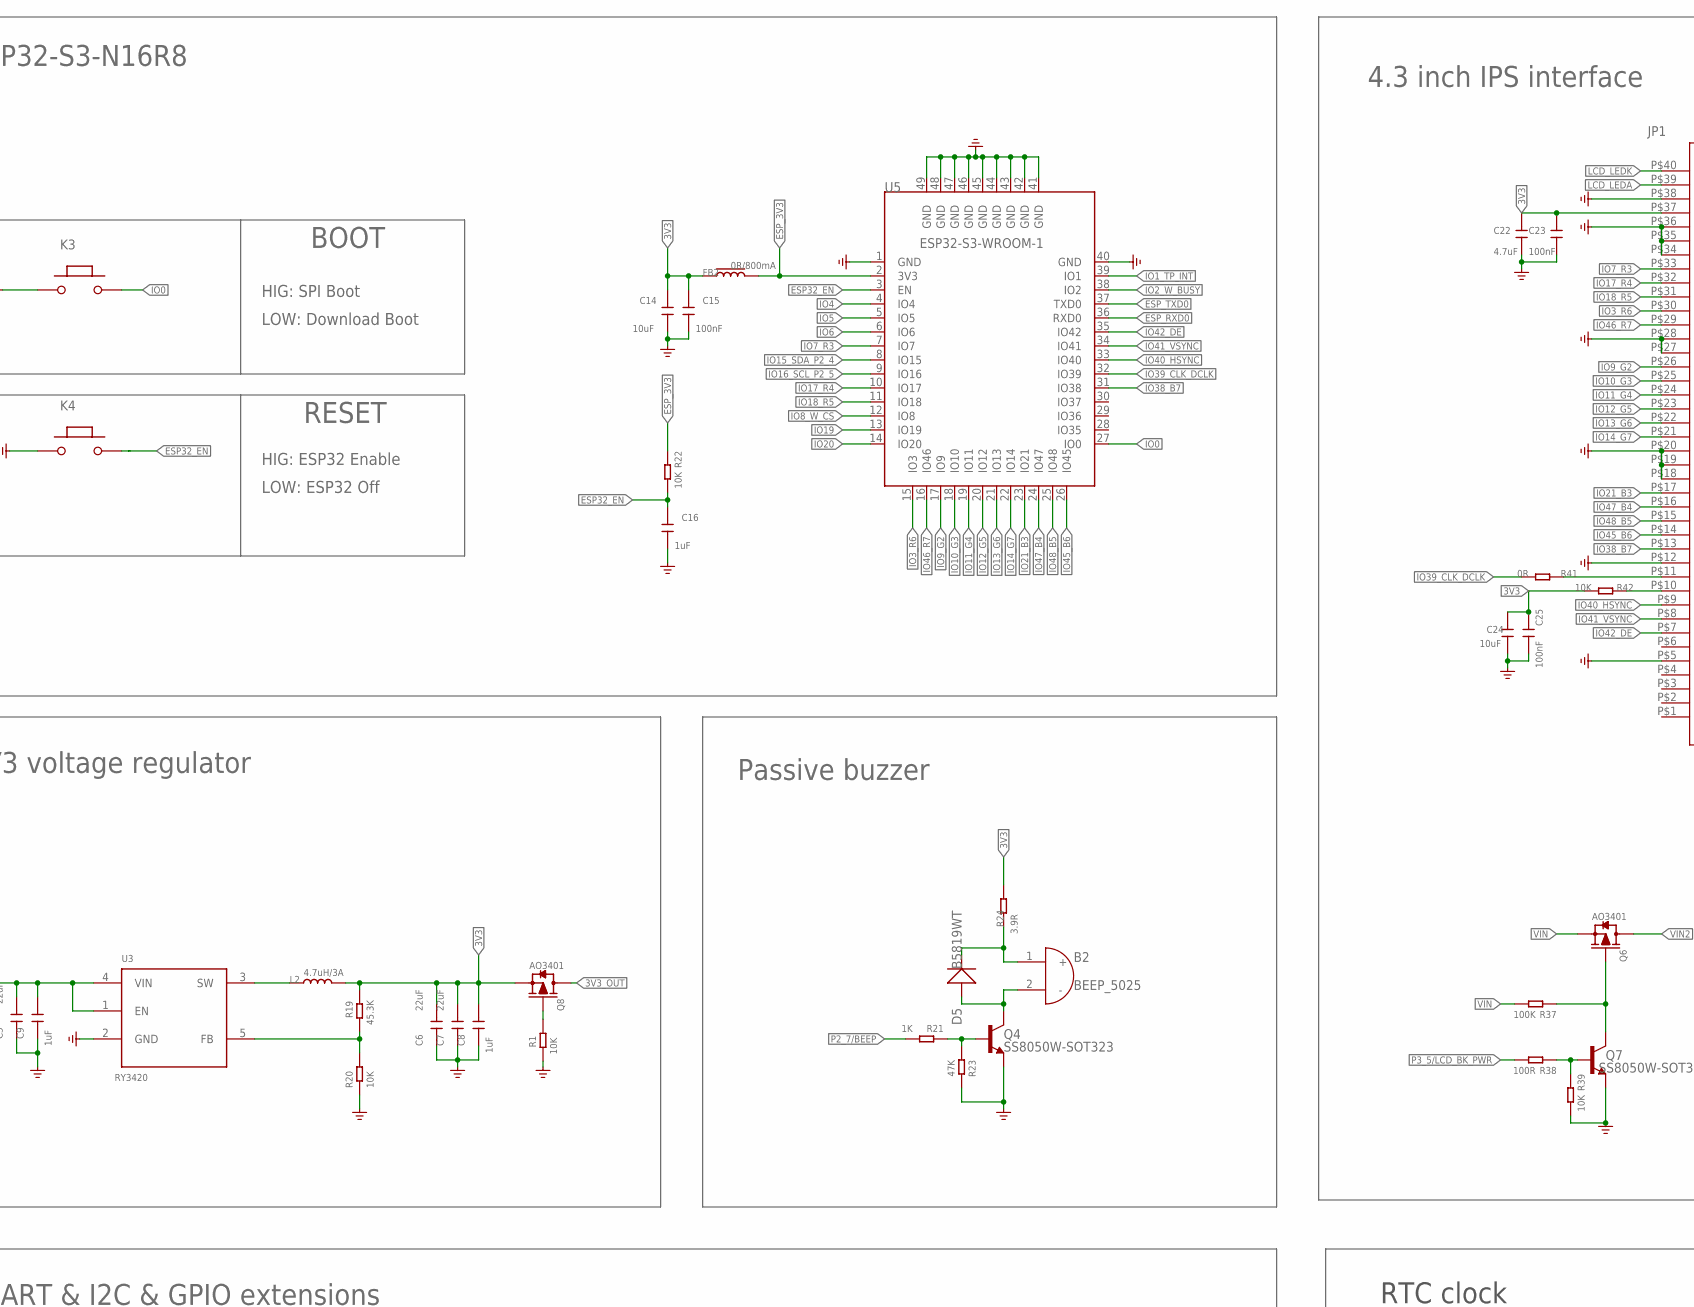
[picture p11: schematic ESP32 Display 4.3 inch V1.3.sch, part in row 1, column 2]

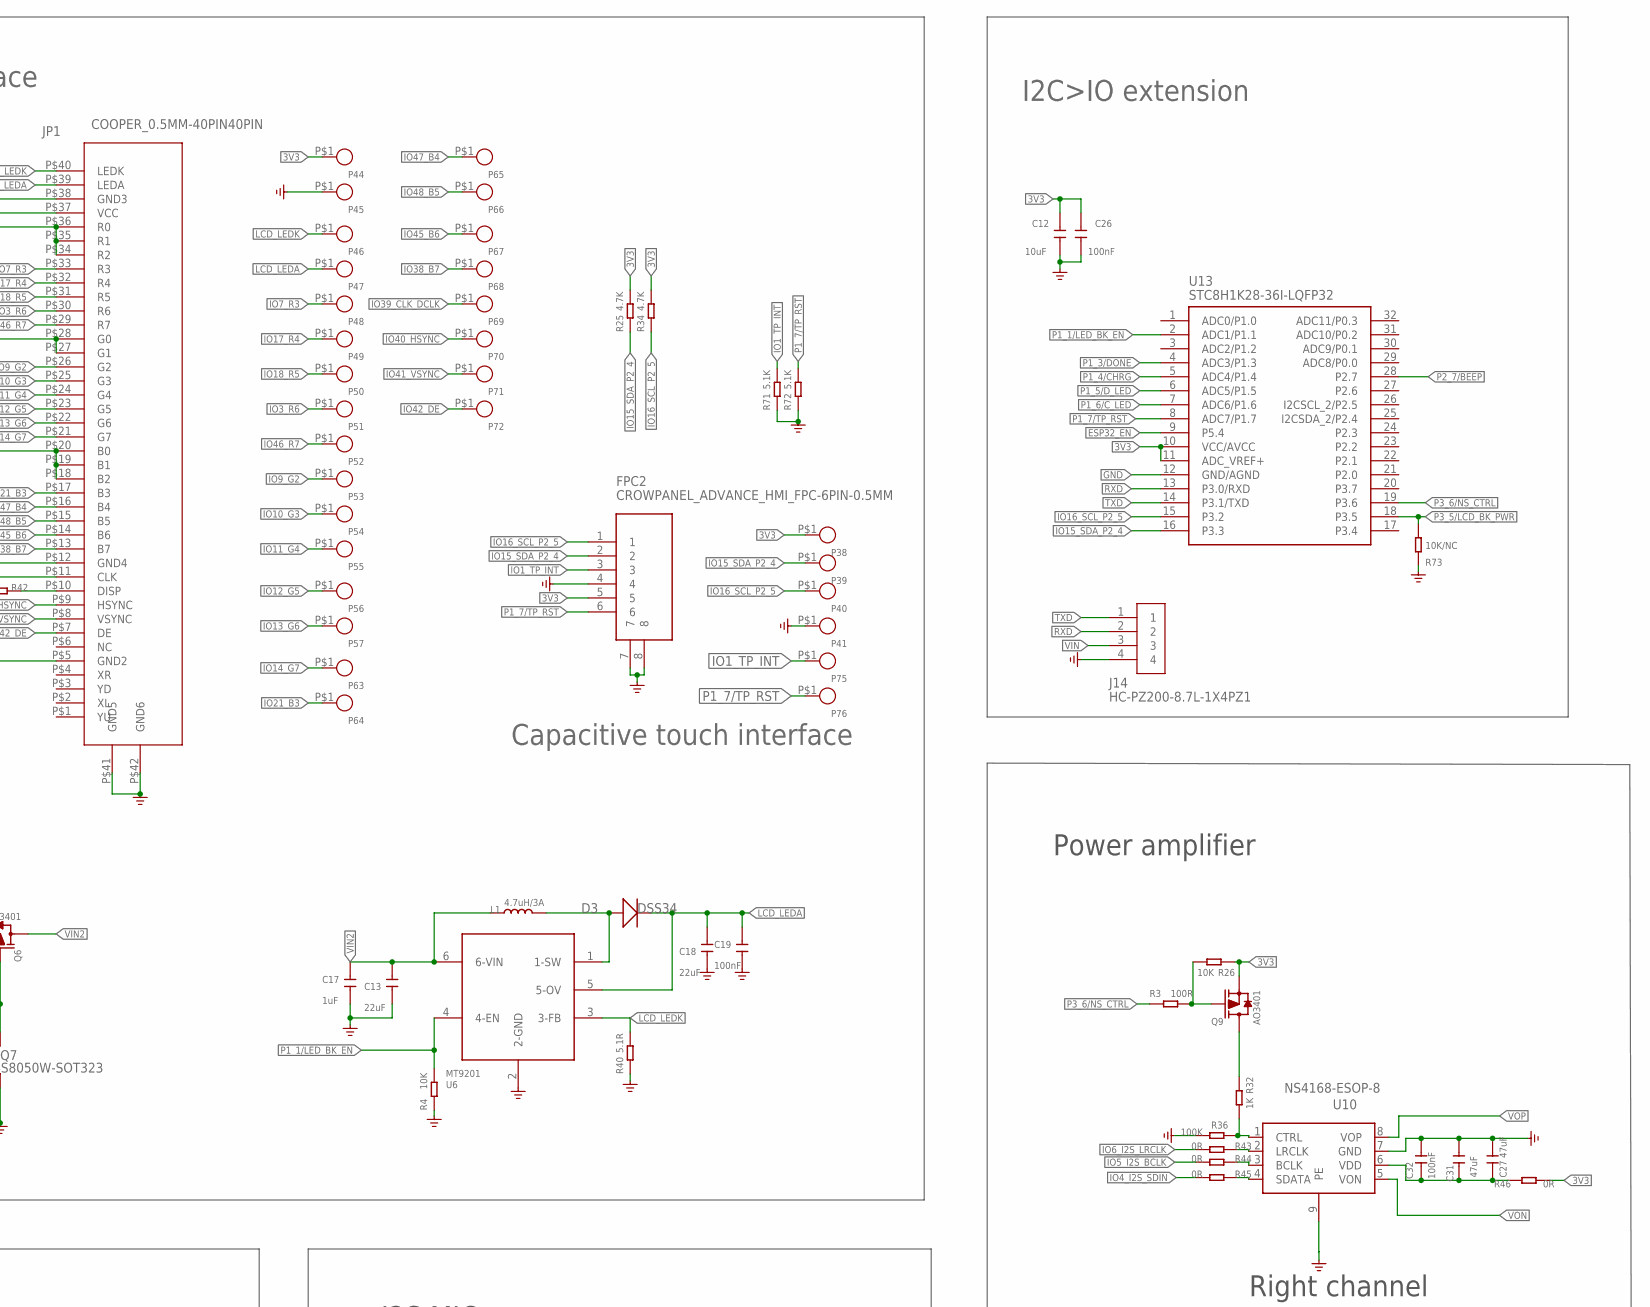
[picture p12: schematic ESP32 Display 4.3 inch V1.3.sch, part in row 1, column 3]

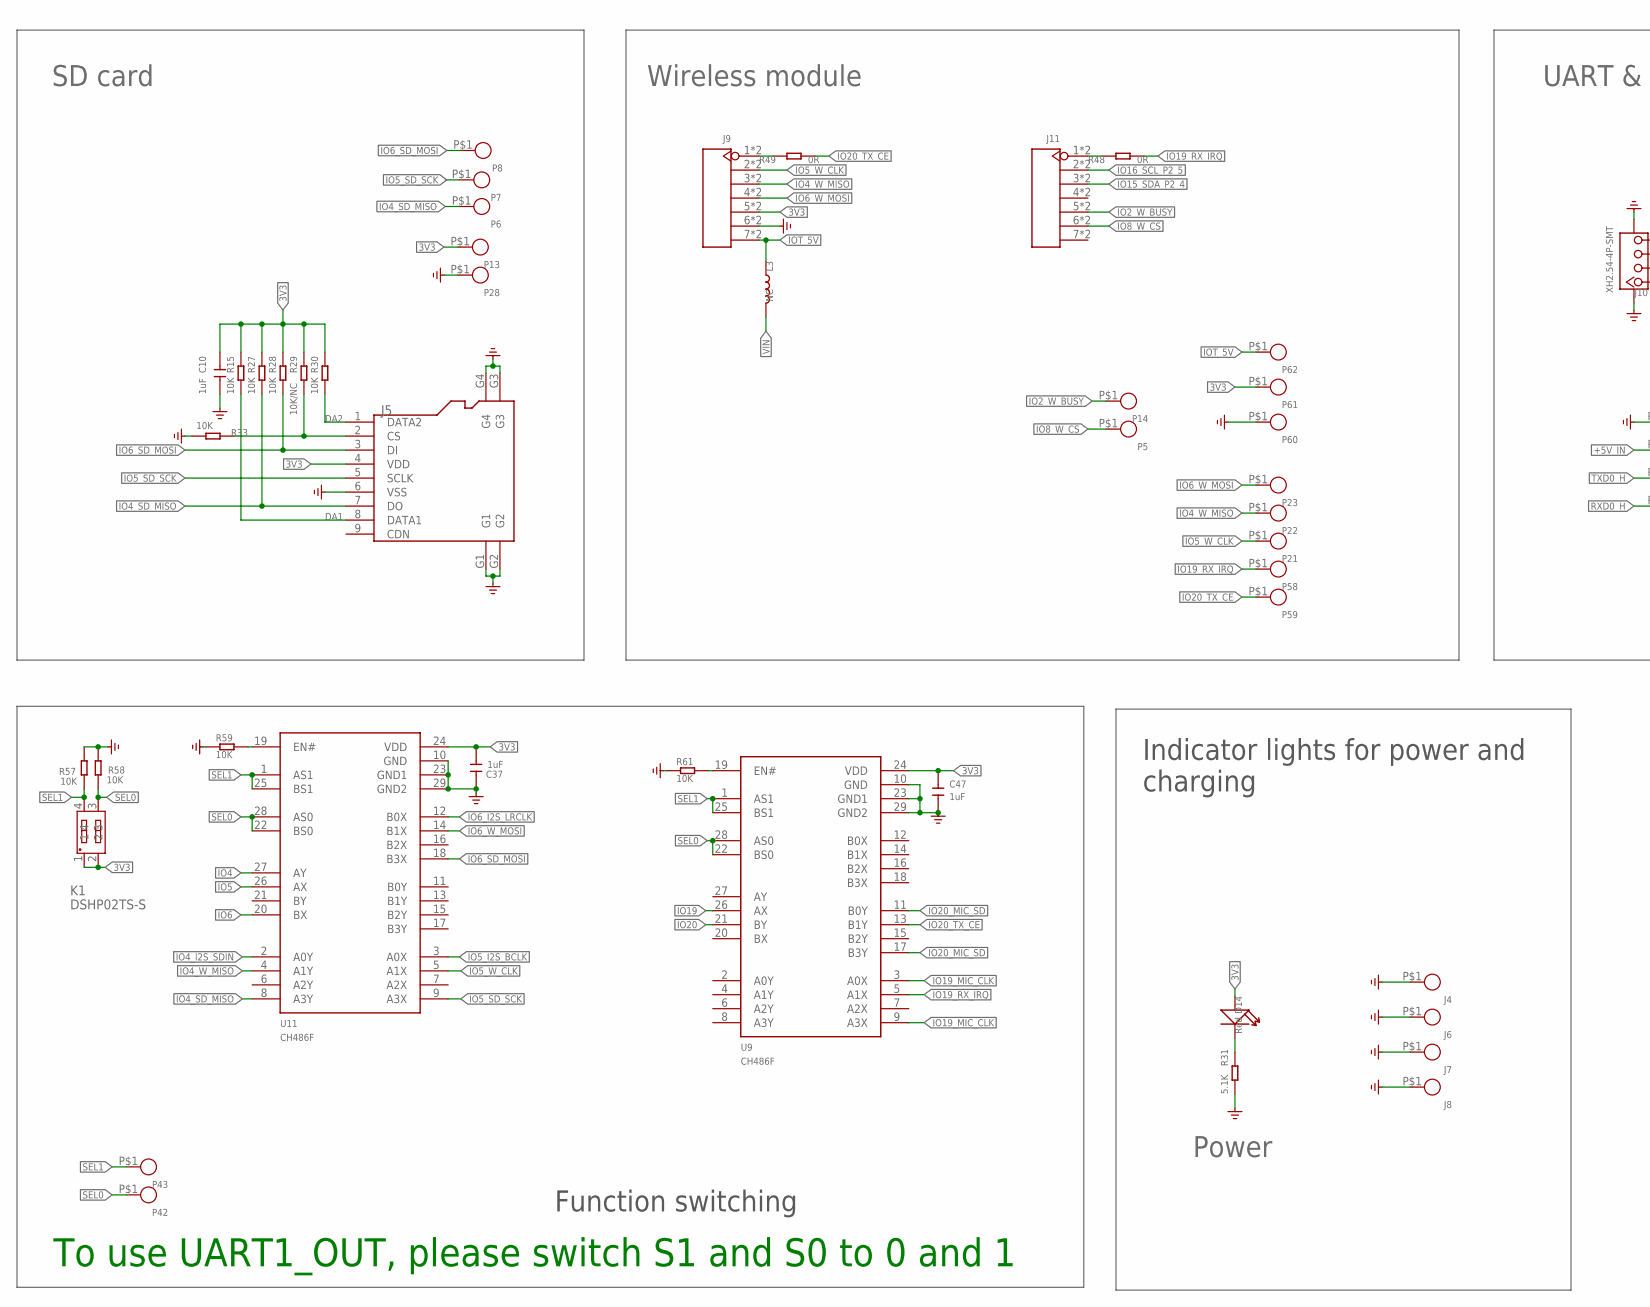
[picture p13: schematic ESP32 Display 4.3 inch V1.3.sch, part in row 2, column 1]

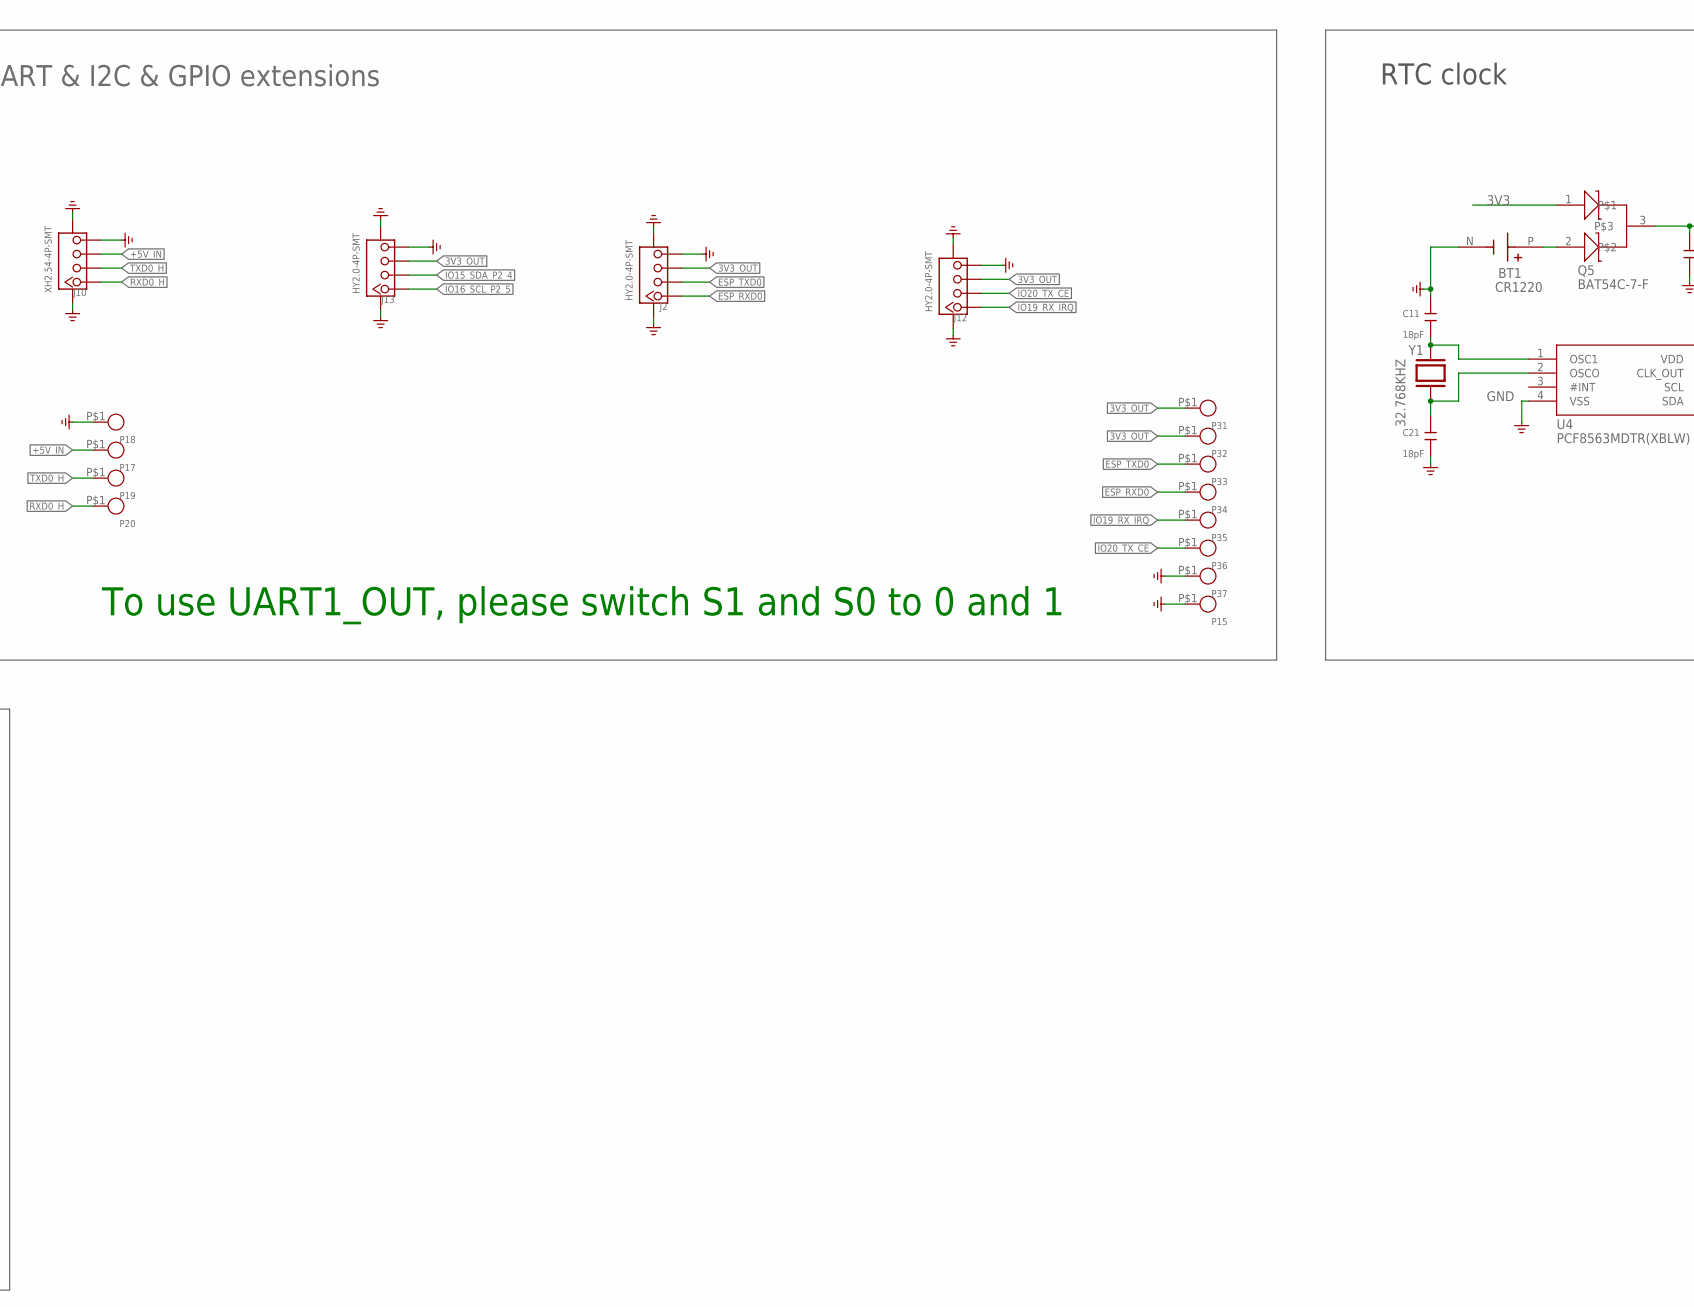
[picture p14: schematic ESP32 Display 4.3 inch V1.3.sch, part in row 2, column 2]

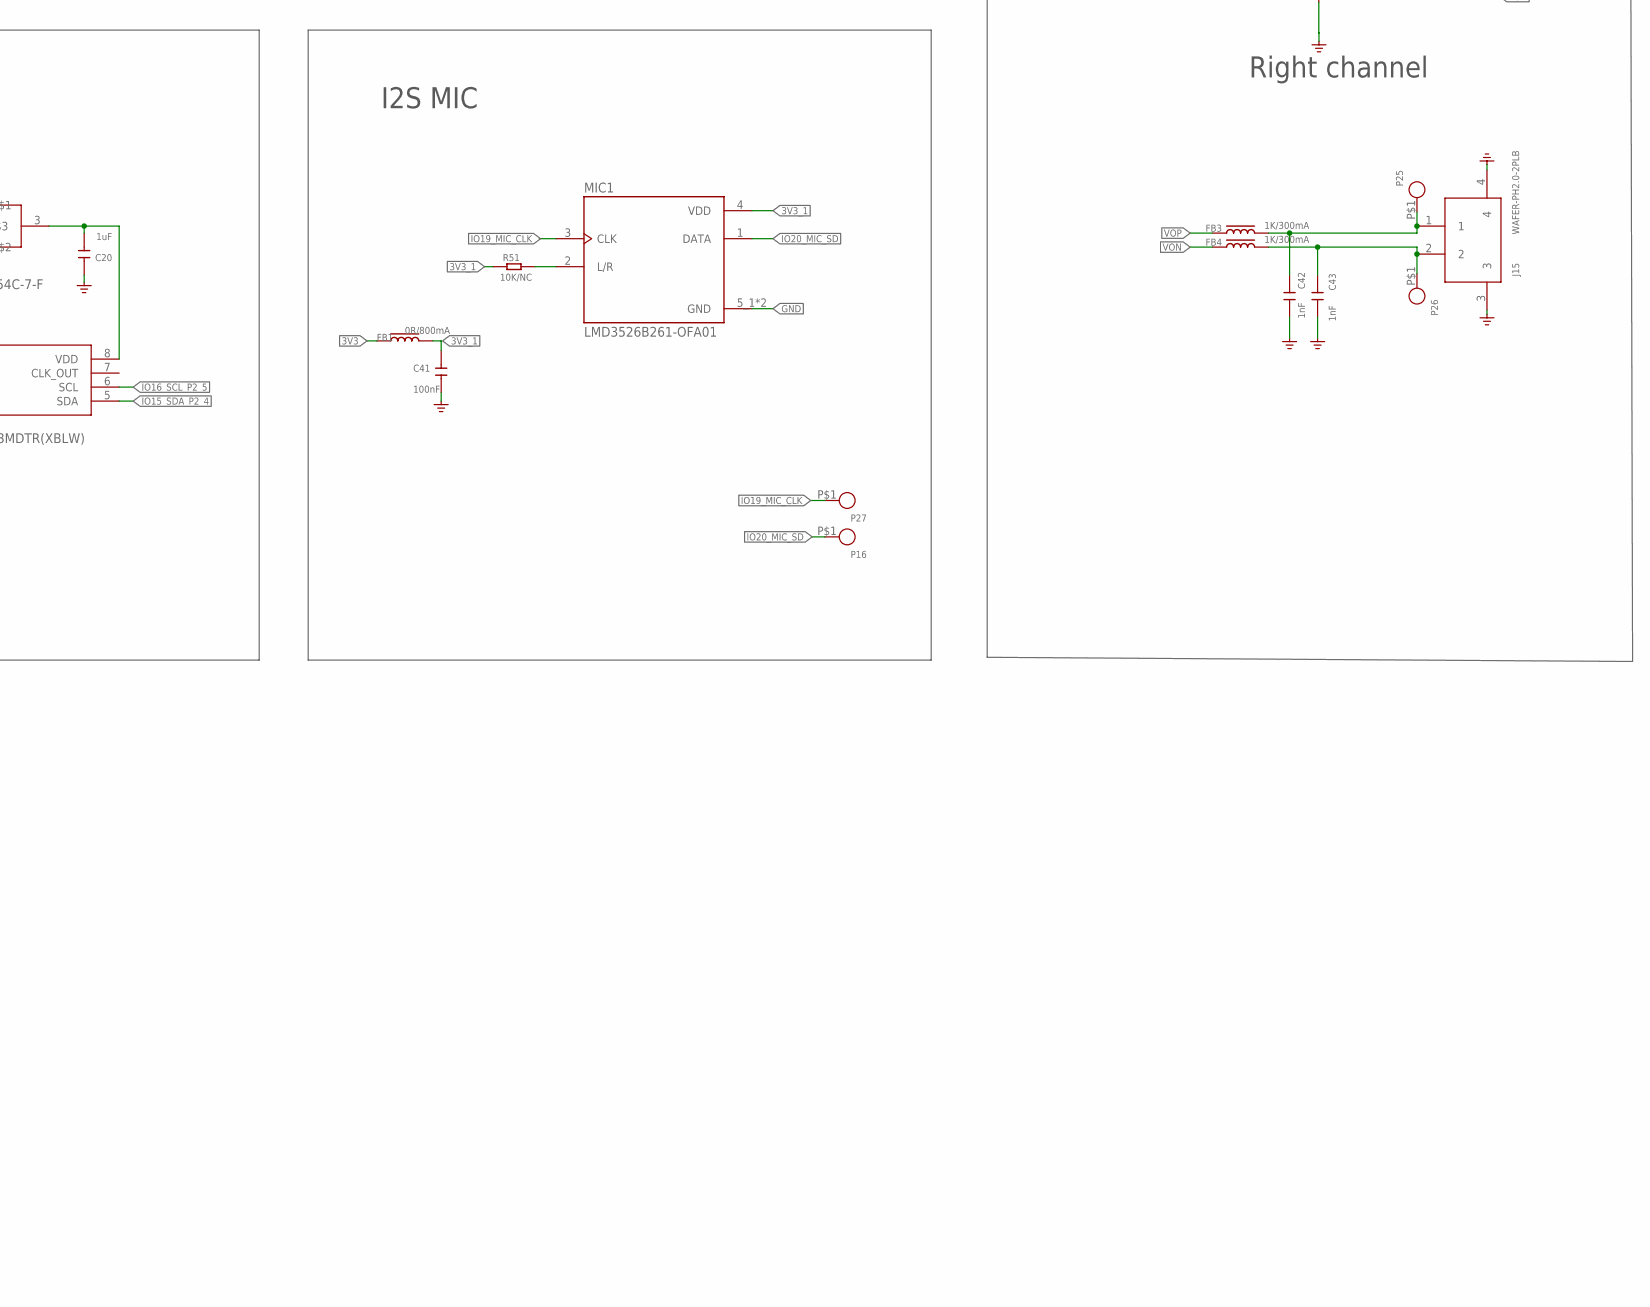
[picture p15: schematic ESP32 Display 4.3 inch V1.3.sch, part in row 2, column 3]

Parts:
B2: BEEP_5025
BT1: CR1220
C1, C2, C3, C8, C9, C10, C16, C17, C20, C37, C47: 1uF; C0603
C4: NC/10uF; C0603
C5, C6, C7, C13, C18: 22uF; C0805
C11, C21: 18pF; C0603
C12, C14, C24: 10uF; C0603
C15, C19, C23, C25, C26, C32, C41: 100nF; C0603
C22: 4.7uF; C0603
C27, C31: 47uF; C0805
C42, C43: 1nF; C0603
D1: KT-0603RYG; LED_KT-0603RYG
D2, D3, D10: DSS34; D_SOD123FL
D5: B5819WT; D_SOD523
D11, D13: 1N5817WS; D_SOD323
D14: Red; LED0603
FB1, FB2: 0R/800mA; L0603
FB3, FB4: 1K/300mA; L0603
FPC2: CROWPANEL_ADVANCE_HMI_FPC-6PIN-0.5MM
J1: TYPEC-3.0-16P-SMD; USB-3.0TYPEC-SMD
J2, J12, J13: HY2.0-4P-SMT; CONNECTOR_4P-SMD-2.0
J3: PH2.0WT-2PIN
J4, J6, J7, J8: THO-M3.25MM-HOLE; THO-M3.2*5MM-HOLE
J5: HOLDER-MICROSD-9P; 9P-SMD-W/-RING
J9, J11: HEADER-7P-18.28X2.5; H7-2.54-18.28X2.5X5MM
J10: XH2.54-4P-SMT; XH2.54-4P-SMD
J14: HC-PZ200-8.7L-1X4PZ1; TEST-PIN-4-2.0MM
J15: WAFER-PH2.0-2PLB; CONN-TH_2P-P2.00_XUNPU_WAFER-PH2.0-2PLB
JP1: COOPER_0.5MM-40PIN40PIN; COOPER_0.5MM*40P
K1: DSHP02TS-S; SW-SMD_DSHP02TS-S_1
K3, K4: BUTTON; 157SW
L1, L2: 4.7uH/3A; L0420
L3: NC; L0603
MIC1: LMD3526B261-OFA01; MIC-SMD_5P-L3.5-W2.7-P1.67
P1, P2, P3, P4, P5, P6, P7, P8, P9, P10, P11, P12, P13, P14, P15, P16, P17, P18, P19, P20, P21, P22, P23, P25, P26, P27, P28, P31, P32, P33, P34, P35, P36, P37, P38, P39, P40, P41, P42, P43, P44, P45, P46, P47, P48, P49, P50, P51, P52, P53, P54, P55, P56, P57, P58, P59, P60, P61, P62, P63, P64, P65, P66, P67, P68, P69, P70, P71, P72, P75, P76: TEST_PADPAD-1.5MM; TEST_PAD-1.5MM
Q1, Q2: BSS138W_SOT323; MOS_SOT323
Q3, Q6, Q8, Q9: AO3401; PMOS_SOT23
Q4, Q7: SS8050W-SOT323; MOS_SOT323
Q5: BAT54C-7-F; SOT-23
R1, R4, R5, R9, R15, R18, R20, R22, R26, R27, R28, R30, R33, R39, R42, R57, R58, R59, R61: 10K; R0603-SP
R2, R16: 2K; R0603-SP
R3, R38: 100R; R0603-SP
R6, R7, R8, R10, R41, R43, R44, R45, R46, R48, R49: 0R; R0603-SP
R11, R12, R13, R14, R25, R34: 4.7K; R0603-SP
R17, R31, R35, R47, R50, R69, R70, R71, R72: 5.1K; R0603-SP
R19: 45.3K; R0603-SP
R21, R32: 1K; R0603-SP
R23: 47K; R0603-SP
R24: 3.9R; R0603-SP
R29, R51, R73: 10K/NC; R0603-SP
R36, R37: 100K; R0603-SP
R40: 5.1R; R0603-SP
U1: CH340K; ESOP-10-EP-150MIL
U2: TP4059-SOT23-6; SOT23-6L
U3: RY3420; IC_SOT23-5
U4: PCF8563MDTR(XBLW); MSOP-8
U5: ESP32-S3-WROOM-1; ESP32-S3-WROOM-1-SMD41
U6: MT9201; COOPER_SOT23-6
U8: UMH3NTN; SOP65P210X100-6N
U9, U11: CH486F; QFN-28_L4.0-W4.0-P0.40-BL-EP2.8
U10: NS4168-ESOP-8
U13: STC8H1K28-36I-LQFP32; QFP80P900X900X165-32N
Y1: 32.768KHZ; SMD3215-2P

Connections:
3V3: C6.2, C7.2, C8.2, C10.2, C12.2, C14.2, C15.2, C22.2, C23.2, C24.2, C25.2, C26.2, C37.2, C47.1, D1.1, D1.2, D14.+, FB1.1, FB2.1, FPC2.5, J5.4 (VDD), J9.5, J9.5-5 (5), JP1.P$37 (VCC), K1.1, K1.2, L2.2, P13.P$1, P38.P$1, P44.P$1, P61.P$1, Q1.1 (G), Q2.1 (G), Q5.1, Q8.2 (S), Q9.2 (S), R11.1, R14.1, R15.2, R19.2, R24.2, R25.2, R26.1, R27.2, R28.2, R29.2, R30.2, R34.2, R42.2, R46.2, U9.24 (VDD), U11.24 (VDD), U13.10 (VCC/AVCC), U13.11 (ADC_VREF+)
3V3$: C2.2, U1.10 (V3)
3V3_1: C41.2, FB1.2, MIC1.4 (VDD), R51.2
3V3_NS_CTRL: Q9.3 (D), R32.1
3V3_OUT: J2.3, J12.3, J13.3, P31.P$1, P32.P$1, Q8.3 (D)
+5V_IN: D2.+, D13.+, J10.3, P17.P$1
+VBUS1: C1.2, D10.+, D11.+, J1.A4, J1.A9, J1.B4, J1.B9, P1.P$1, U1.7 (VCC)
+VC_IN: C3.2, D11.-, D13.-, Q3.1 (G), R17.2, R18.2, R47.2, R50.2, U2.4 (VCC)
DA1: J5.8 (DATA1), R15.1
DA2: J5.1 (DATA2), R30.1
DTR: R5.2, U1.4 (DTR#), U8.4 (E2)
ESP32_EN: C16.2, K4.2, R22.2, U5.3 (EN), U8.6 (C1), U13.9 (P5.4)
ESP_3V3: FB2.2, R22.1, U5.2 (3V3)
ESP_RXD0: J2.1, P34.P$1, Q2.2 (S), R11.2, U5.36 (RXD0)
ESP_TXD0: J2.2, P33.P$1, Q1.2 (S), R14.2, U5.37 (TXD0)
GND: BT1.N (-), C1.1, C2.1, C3.1, C4.1, C5.1, C6.1, C7.1, C8.1, C9.1, C10.1, C11.2, C12.1, C13.2, C14.1, C15.1, C16.1, C17.1, C18.2, C19.1, C20.2, C21.1, C22.1, C23.1, C24.1, C25.1, C26.1, C27.2, C31.2, C32.2, C37.1, C41.1, C42.1, C43.1, C47.2, FPC2.4, FPC2.7, FPC2.8, J1.A1, J1.A12, J1.B1, J1.B12, J1.P$1, J1.P$2, J1.P$3, J1.P$4, J2.4, J2.SS1, J2.SS2, J3.P$2, J3.P$3, J3.P$4, J4.P$1, J5.6 (VSS), J5.G1, J5.G2, J5.G3, J5.G4, J6.P$1, J7.P$1, J8.P$1, J9.6, J9.6-6 (6), J10.4, J10.5 (SS1), J10.6 (SS2), J12.4, J12.SS1, J12.SS2, J13.4, J13.SS1, J13.SS2, J14.4, J15.3, J15.4, JP1.P$5 (GND2), JP1.P$12 (GND4), JP1.P$18 (B2), JP1.P$19 (B1), JP1.P$20 (B0), JP1.P$27 (G1), JP1.P$28 (G0), JP1.P$34 (R2), JP1.P$35 (R1), JP1.P$36 (R0), JP1.P$38 (GND3), JP1.P$41 (GND5), JP1.P$42 (GND6), K3.1, K4.1, MIC1.5_1 (GND), MIC1.5_2 (GND), P4.P$1, P10.P$1, P12.P$1, P15.P$1, P18.P$1, P28.P$1, P37.P$1, P41.P$1, P45.P$1, P60.P$1, Q4.2 (E), Q7.2 (E), R1.1, R4.1, R16.1, R18.1, R20.1, R23.2, R31.1, R33.2, R36.2, R39.2, R40.1, R57.2, R58.2, R59.2, R61.2, R69.1, R70.2, R71.1, R72.1, R73.1, U1.3 (GND), U1.EP, U2.2 (GND), U3.2 (GND), U4.4 (VSS), U5.1 (GND), U5.40 (GND), U5.41 (GND), U5.42 (GND), U5.43 (GND), U5.44 (GND), U5.45 (GND), U5.46 (GND), U5.47 (GND), U5.48 (GND), U5.49 (GND), U6.2 (2-GND), U9.10 (GND), U9.23 (GND1), U9.29 (GND2), U10.7 (GND), U10.9 (PE), U11.10 (GND), U11.23 (GND1), U11.29 (GND2), U13.12 (GND/AGND)
IO0: K3.2, U5.27 (IO0), U8.3 (C2)
IO1_TP_INT: FPC2.3, P75.P$1, R71.2, U5.39 (IO1)
IO2_W_BUSY: J11.5, J11.5-5 (5), P14.P$1, U5.38 (IO2)
IO3_R6: JP1.P$30 (R6), P51.P$1, U5.15 (IO3)
IO4: U5.4 (IO4), U11.27 (AY)
IO4_I2S_SDIN: R45.2, U11.2 (A0Y)
IO4_SD_MISO: J5.7 (DO), P6.P$1, R27.1, U11.8 (A3Y)
IO4_W_MISO: J9.3, J9.3-3 (3), P22.P$1, U11.4 (A1Y)
IO5: U5.5 (IO5), U11.26 (AX)
IO5_I2S_BCLK: R44.2, U11.3 (A0X)
IO5_SD_SCK: J5.5 (SCLK), P7.P$1, U11.9 (A3X)
IO5_W_CLK: J9.2, J9.2-2 (2), P21.P$1, U11.5 (A1X)
IO6: U5.6 (IO6), U11.20 (BX)
IO6_I2S_LRCLK: R43.2, U11.12 (B0X)
IO6_SD_MOSI: J5.3 (DI), P8.P$1, R28.1, U11.18 (B3X)
IO6_W_MOSI: J9.4, J9.4-4 (4), P23.P$1, U11.14 (B1X)
IO7_R3: JP1.P$33 (R3), P48.P$1, U5.7 (IO7)
IO8_W_CS: J11.6, J11.6-6 (6), P5.P$1, U5.12 (IO8)
IO9_G2: JP1.P$26 (G2), P53.P$1, U5.17 (IO9)
IO10_G3: JP1.P$25 (G3), P54.P$1, U5.18 (IO10)
IO11_G4: JP1.P$24 (G4), P55.P$1, U5.19 (IO11)
IO12_G5: JP1.P$23 (G5), P56.P$1, U5.20 (IO12)
IO13_G6: JP1.P$22 (G6), P57.P$1, U5.21 (IO13)
IO14_G7: JP1.P$21 (G7), P63.P$1, U5.22 (IO14)
IO15_SDA_P2_4: FPC2.2, J11.3, J11.3-3 (3), J13.2, P39.P$1, R25.1, U4.5 (SDA), U5.8 (IO15), U13.16 (P3.3)
IO16_SCL_P2_5: FPC2.1, J11.2, J11.2-2 (2), J13.1, P40.P$1, R34.1, U4.6 (SCL), U5.9 (IO16), U13.15 (P3.2)
IO17_R4: JP1.P$32 (R4), P49.P$1, U5.10 (IO17)
IO18_R5: JP1.P$31 (R5), P50.P$1, U5.11 (IO18)
IO19: U5.13 (IO19), U9.26 (AX)
IO19_MIC_CLK: MIC1.3 (CLK), P27.P$1, U9.3 (A0X), U9.9 (A3X)
IO19_RX_IRQ: J12.1, P35.P$1, P58.P$1, R48.2, U9.5 (A1X)
IO20: U5.14 (IO20), U9.21 (BY)
IO20_MIC_SD: MIC1.1 (DATA), P16.P$1, U9.11 (B0Y), U9.17 (B3Y)
IO20_TX_CE: J12.2, P36.P$1, P59.P$1, R49.2, U9.13 (B1Y)
IO21_B3: JP1.P$17 (B3), P64.P$1, U5.23 (IO21)
IO38_B7: JP1.P$13 (B7), P68.P$1, U5.31 (IO38)
IO39_CLK_DCLK: P69.P$1, R41.2, U5.32 (IO39)
IO40_HSYNC: JP1.P$9 (HSYNC), P70.P$1, U5.33 (IO40)
IO41_VSYNC: JP1.P$8 (VSYNC), P71.P$1, U5.34 (IO41)
IO42_DE: JP1.P$7 (DE), P72.P$1, U5.35 (IO42)
IO45_B6: JP1.P$14 (B6), P67.P$1, U5.26 (IO45)
IO46_R7: JP1.P$29 (R7), P52.P$1, U5.16 (IO46)
IO47_B4: JP1.P$16 (B4), P65.P$1, U5.24 (IO47)
IO48_B5: JP1.P$15 (B5), P66.P$1, U5.25 (IO48)
IOT_5V: J9.7, J9.7-7 (7), L3.1, P62.P$1
LCD_LEDA: C18.1, C19.2, D3.-, JP1.P$39 (LEDA), P47.P$1, U6.5 (5-OV)
LCD_LEDK: JP1.P$40 (LEDK), P46.P$1, R40.2, U6.3 (3-FB)
unnamed: Q8.1 (G), R1.2
unnamed: D1.3, R2.1
unnamed: D1.4, R35.1
unnamed: D14.-, R31.2
unnamed: R6.1, U1.1 (UD+)
unnamed: R7.1, U1.2 (UD-)
unnamed: R5.1, U8.2 (B1)
unnamed: R9.1, U8.5 (B2)
unnamed: Q9.1 (G), R3.2, R26.2
unnamed: R8.2, U1.9 (RXD)
unnamed: R10.2, U1.8 (TXD)
unnamed: R16.2, U2.6 (PRO)
unnamed: L2.1, U3.3 (SW)
unnamed: R19.1, R20.2, U3.5 (FB)
unnamed: Q4.1 (B), R21.1, R23.1
unnamed: B2.2 (-), D5.+, Q4.3 (C)
unnamed: B2.1 (+), D5.-, R24.1
unnamed: BT1.P (+), Q5.2
unnamed: R32.2, R36.1, U10.1 (CTRL)
unnamed: MIC1.2 (L/R), R51.1
unnamed: D3.+, L1.2, U6.1 (1-SW)
unnamed: J9.1, J9.1-1 (1), R49.1
unnamed: J11.1, J11.1-1 (1), R48.1
unnamed: C20.1, Q5.3, U4.8 (VDD)
unnamed: C21.2, U4.2 (OSCO), Y1.2
unnamed: R43.1, U10.2 (LRCLK)
unnamed: Q6.1 (G), Q7.3 (C), R37.1
unnamed: C11.1, U4.1 (OSC1), Y1.1
unnamed: R44.1, U10.3 (BCLK)
unnamed: Q7.1 (B), R38.1, R39.1
unnamed: R45.1, U10.4 (SDATA)
unnamed: J1.B5, R69.2
unnamed: R61.1, U9.19 (EN#)
unnamed: C27.1, C31.1, C32.1, R46.1, U10.6 (VDD)
unnamed: R59.1, U11.19 (EN#)
unnamed: J1.A5, R70.1
unnamed: JP1.P$11 (CLK), R41.1
unnamed: JP1.P$10 (DISP), R42.1
P1_1/LED_BK_EN: R4.2, U6.4 (4-EN), U13.2 (ADC1/P1.1)
P1_3/DONE: R47.1, U2.5 (STD), U13.4 (ADC3/P1.3)
P1_4/CHRG: R50.1, U2.1 (CHG), U13.5 (ADC4/P1.4)
P1_5/D_LED: R2.2, U13.6 (ADC5/P1.5)
P1_6/C_LED: R35.2, U13.7 (ADC6/P1.6)
P1_7/TP_RST: FPC2.6, P76.P$1, R72.2, U13.8 (ADC7/P1.7)
P2_7/BEEP: R21.2, U13.28 (P2.7)
P3_5/LCD_BK_PWR: R38.2, R73.2, U13.18 (P3.5)
P3_6/NS_CTRL: R3.1, U13.19 (P3.6)
ROUT+: C42.2, FB3.2, J15.1, P25.P$1
ROUT-: C43.2, FB4.2, J15.2, P26.P$1
RTS: R9.2, U1.6 (RTS#), U8.1 (E1)
RXD: J14.2, U13.13 (P3.0/RXD)
RXD0_H: J10.1, P20.P$1, Q2.3 (D), R10.1, R12.2
SDCS: J5.2 (CS), R29.1, R33.1
SEL0: K1.3, P42.P$1, R58.1, U9.22 (BS0), U9.28 (AS0), U11.22 (BS0), U11.28 (AS0)
SEL1: K1.4, P43.P$1, R57.1, U9.1 (AS1), U9.25 (BS1), U11.1 (AS1), U11.25 (BS1)
TXD: J14.1, U13.14 (P3.1/TXD)
TXD0_H: J10.2, P19.P$1, Q1.3 (D), R8.1, R13.2
USB_D+: J1.A6, J1.B6, P2.P$1, R6.2
USB_D-: J1.A7, J1.B7, P3.P$1, R7.2
VBAT: C4.2, J3.P$1, P9.P$1, Q3.3 (D), R17.1, U2.3 (BAT)
VIN: C5.2, C9.2, D2.-, D10.-, J14.3, L3.2, P11.P$1, Q3.2 (S), Q6.2 (S), R12.1, R13.1, R37.2, U3.1 (EN), U3.4 (VIN)
VIN2: C13.1, C17.2, L1.1, Q6.3 (D), U6.6 (6-VIN)
VON: FB4.1, U10.5 (VON)
VOP: FB3.1, U10.8 (VOP)

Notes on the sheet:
BOOT
RESET
HIG: SPI Boot
LOW: Download Boot
HIG: ESP32 Enable
LOW: ESP32 Off
Power
USB interface
Automatic download circuit
Battery and control
RTC clock
ESP32-S3-N16R8
4.3 inch IPS interface
Capacitive touch interface
Passive buzzer
3V3 voltage regulator
SD card
Wireless module
UART & I2C & GPIO extensions
Indicator lights for power and charging
I2C>IO extension
I2S MIC
Power amplifier
Right channel
Function switching
To use UART1_OUT, please switch S1 and S0 to 0 and 1

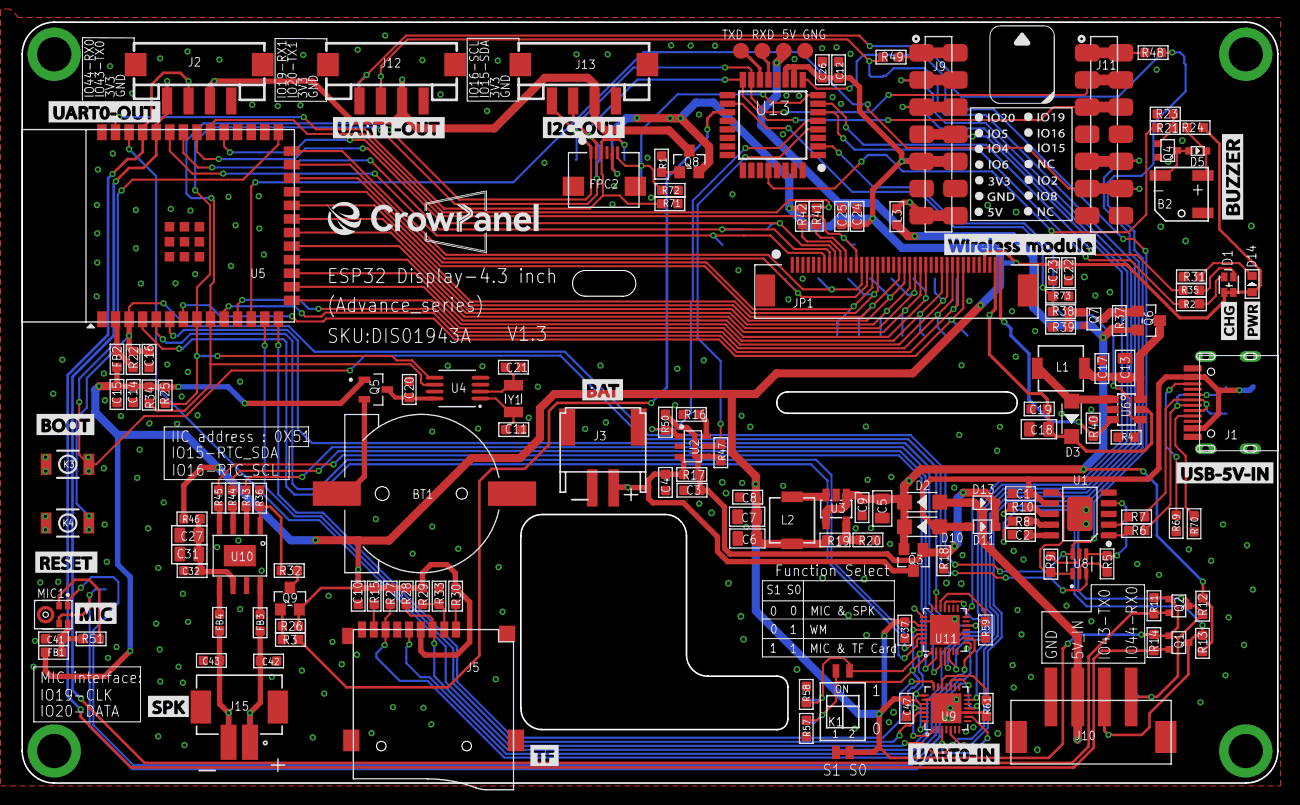
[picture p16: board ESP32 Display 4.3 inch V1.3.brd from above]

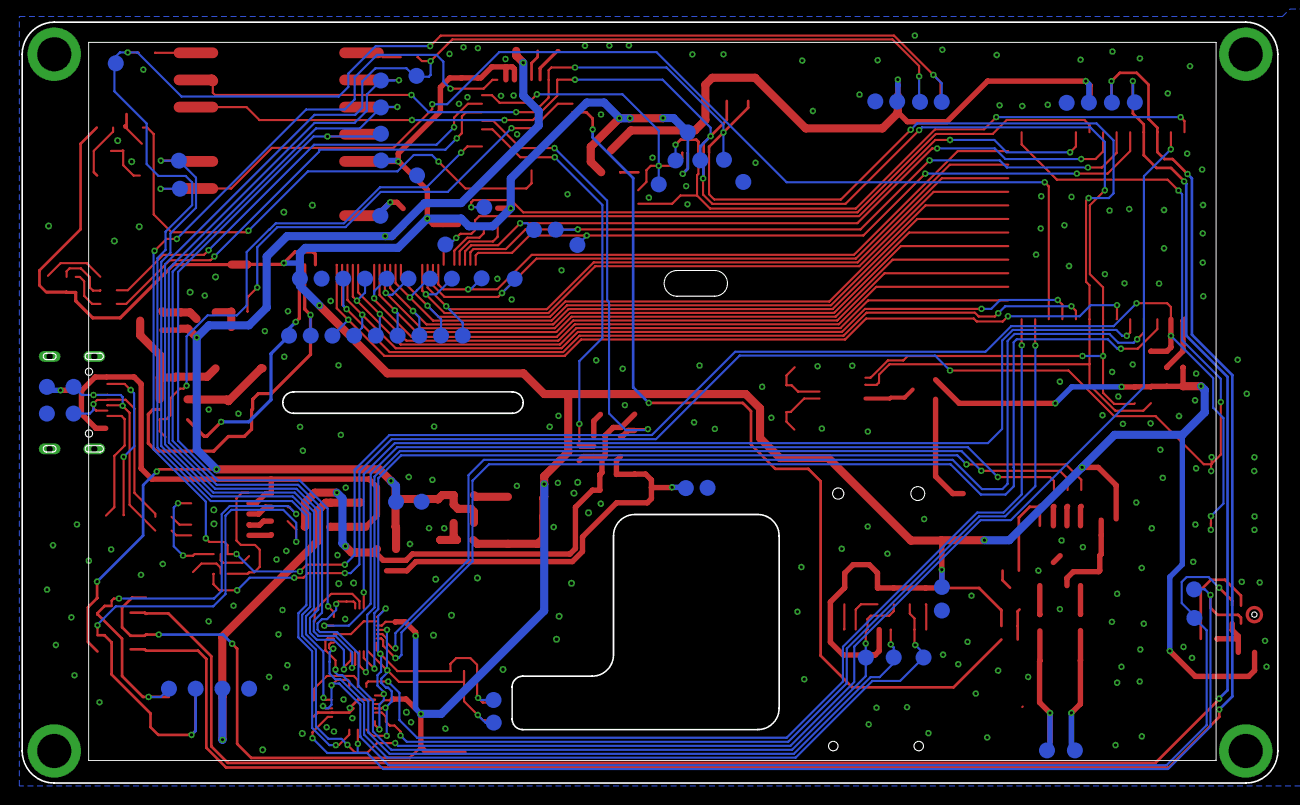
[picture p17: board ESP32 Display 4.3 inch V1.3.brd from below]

Board: 2 copper layers, 117.5 x 71.2 mm, 224 parts (71 on the bottom side), 127 nets.

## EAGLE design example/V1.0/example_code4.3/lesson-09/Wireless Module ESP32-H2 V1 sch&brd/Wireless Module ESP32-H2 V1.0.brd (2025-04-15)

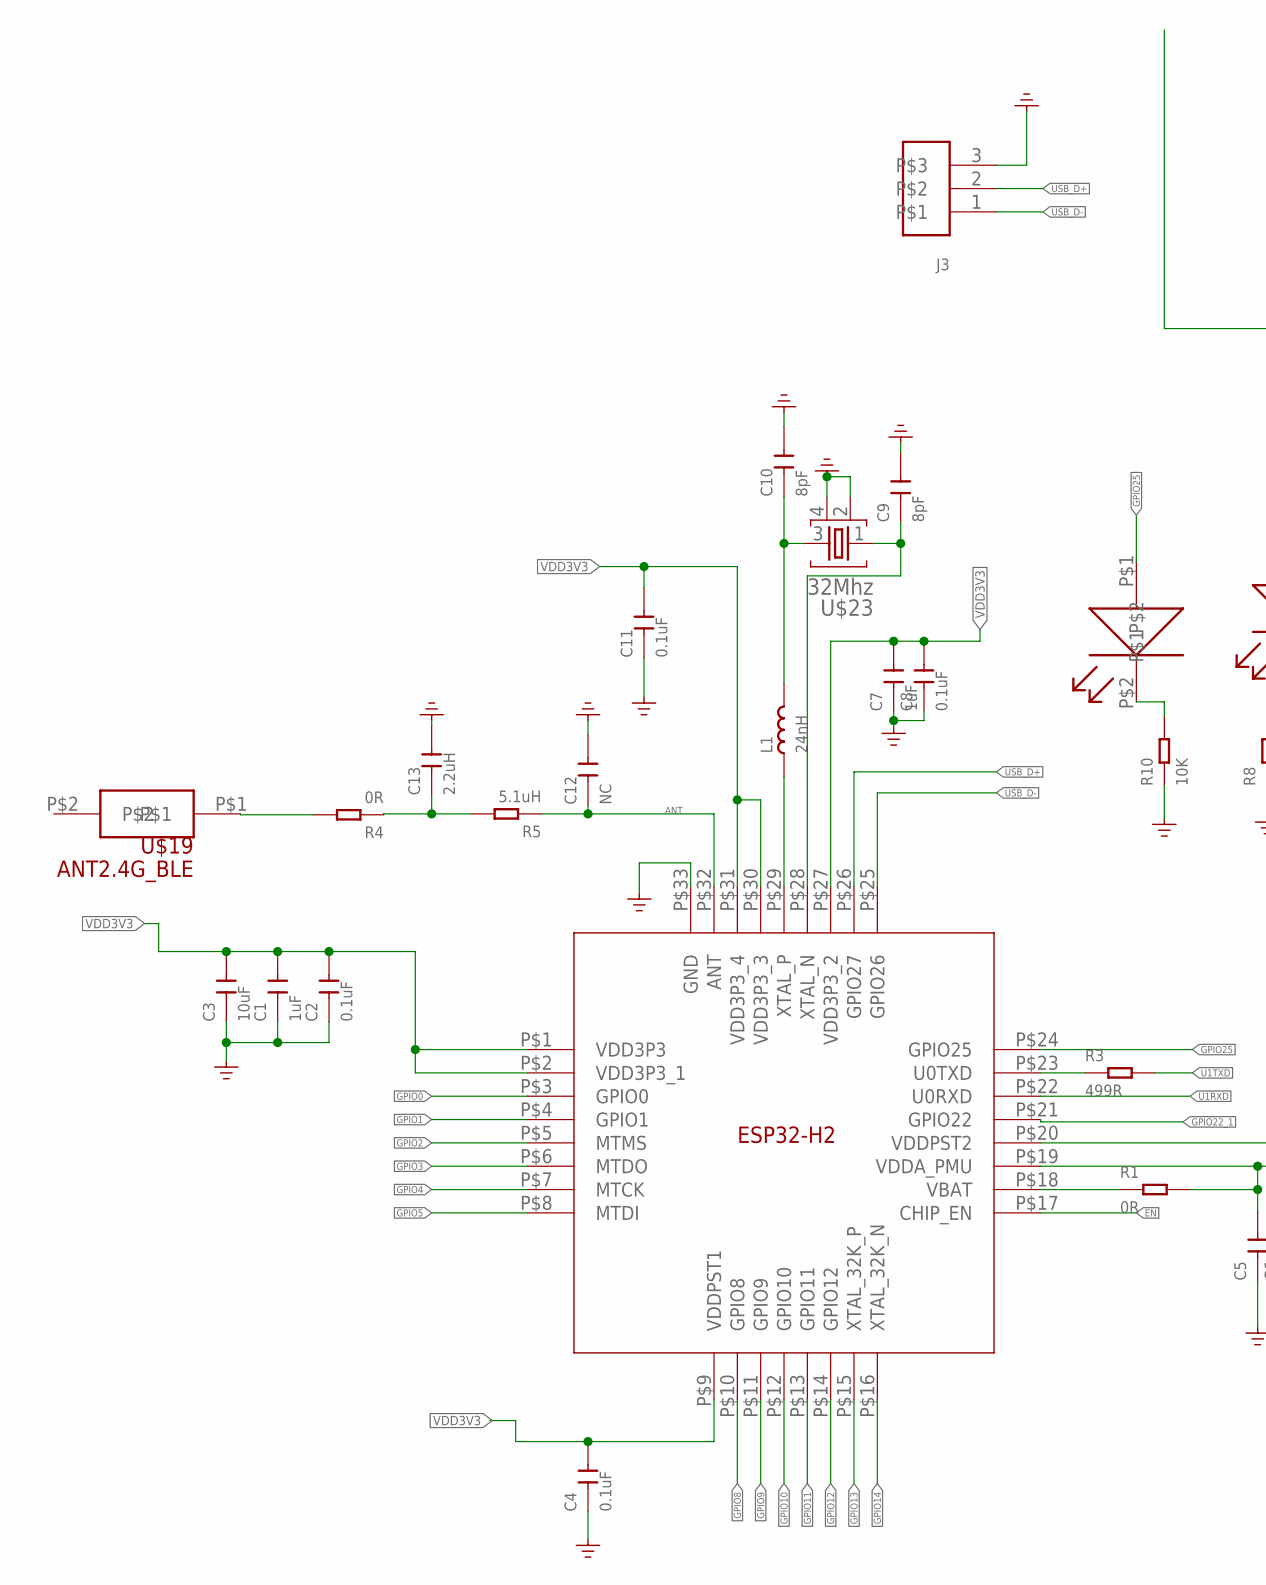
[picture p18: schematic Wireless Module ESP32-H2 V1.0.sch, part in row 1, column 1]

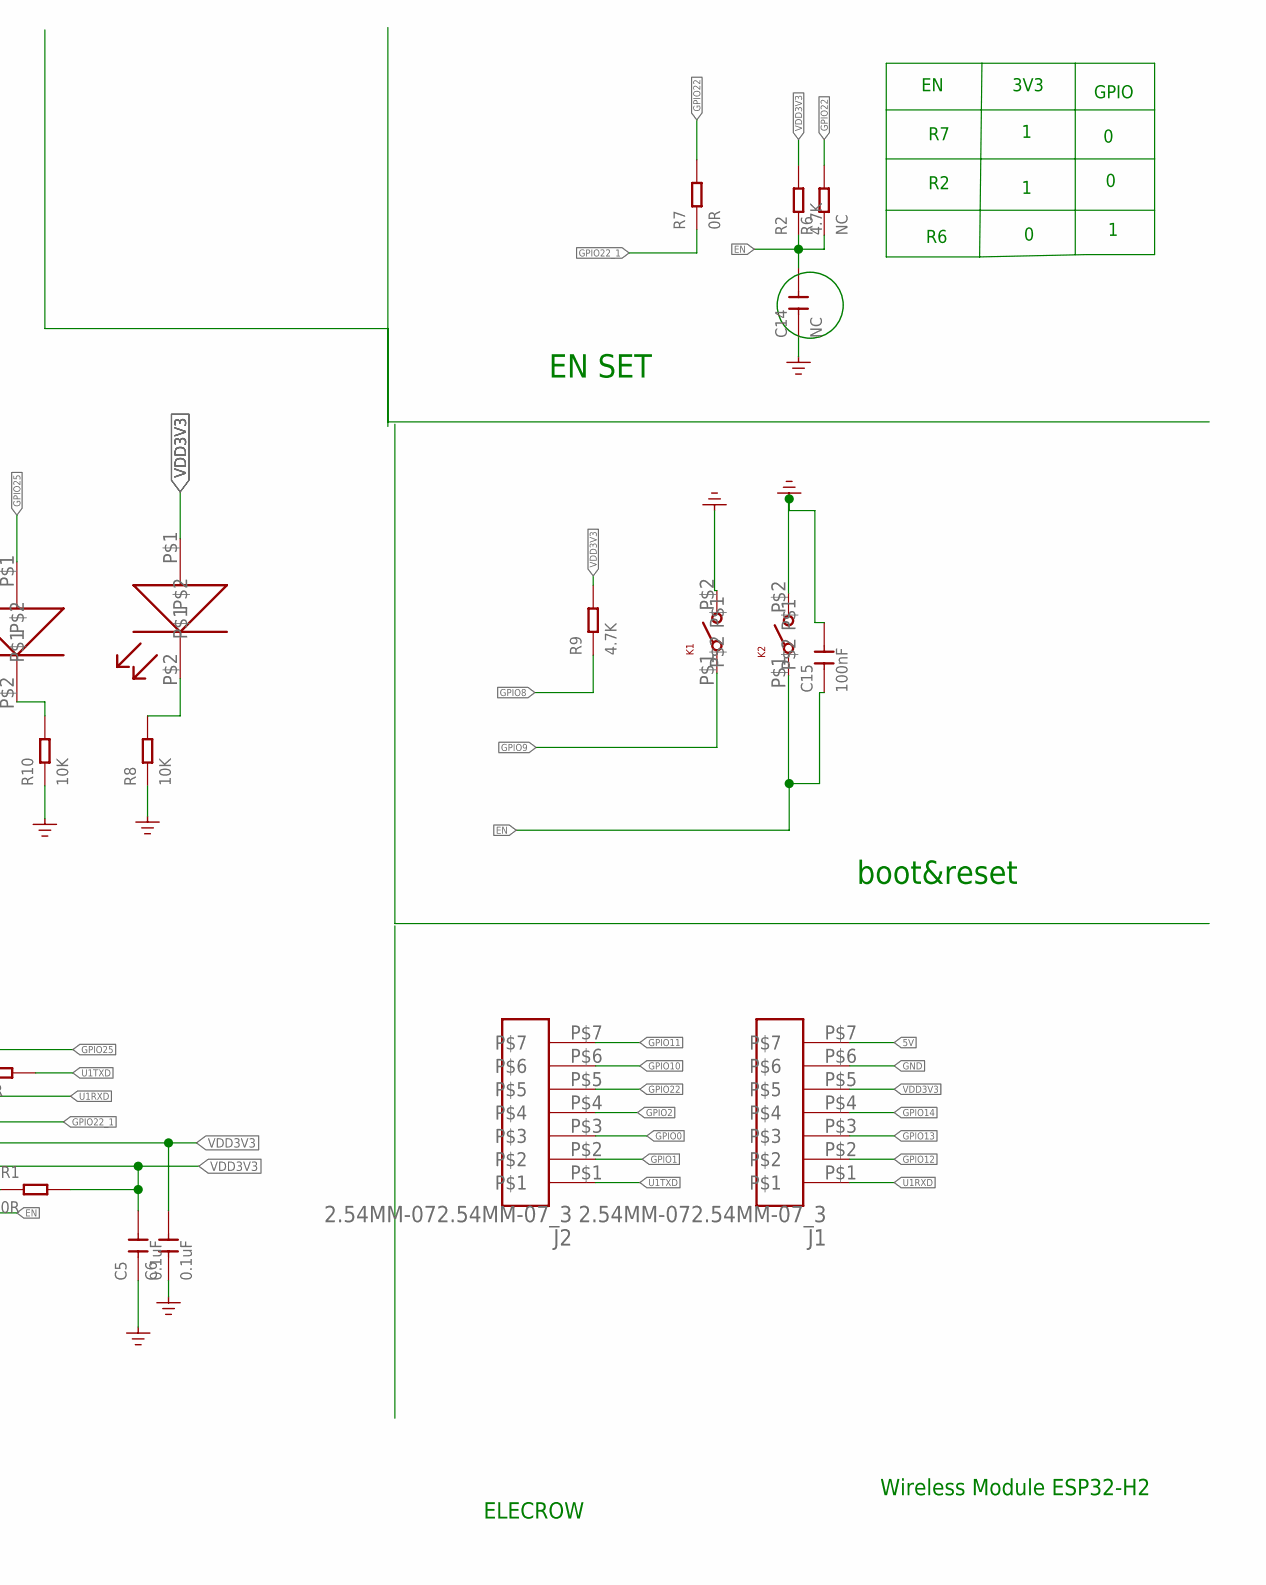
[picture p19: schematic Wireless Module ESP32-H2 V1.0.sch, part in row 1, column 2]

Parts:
C1, C7: 1uF; DISCRETE-NEW_C0402
C2, C4, C5, C6, C8, C11: 0.1uF; DISCRETE-NEW_C0402
C3: 10uF; DISCRETE-NEW_C0402
C9, C10: 8pF; DISCRETE-NEW_C0402
C12, C14: NC; DISCRETE-NEW_C0402
C13: 2.2uH; DISCRETE-NEW_C0402
C15: 100nF; DISCRETE-NEW_C0402
J1, J2: 2.54MM-072.54MM-07_3; 2.54MM-07_3
J3: 1.27MM-3P
K1, K2: KEY_SMD; KEY_3*2.5
L1: 24nH; DISCRETE-NEW_L0402
LED1, LED2: LED_SMT; LED_0402
R1, R4, R7: 0R; DISCRETE-NEW_R0402
R2, R9: 4.7K; DISCRETE-NEW_R0402
R3: 499R; DISCRETE-NEW_R0402
R5: 5.1uH; DISCRETE-NEW_R0402
R6: NC; DISCRETE-NEW_R0402
R8, R10: 10K; DISCRETE-NEW_R0402
U$1: ESP32-H2
U$19: ANT2.4G_BLE; 2.4G_BLE
U$23: 32Mhz; NORDIC_NRF_BT-XTAL_2016_N

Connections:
5V: J1.P$7
ANT: C12.1, R5.1, U$1.P$32 (ANT)
EN: C14.2, C15.1, K2.P$1, R2.1, R6.1, U$1.P$17 (CHIP_EN)
GND: C1.1, C2.1, C3.1, C4.1, C5.1, C6.1, C7.1, C8.1, C9.2, C10.2, C11.1, C12.2, C13.2, C14.1, C15.2, J1.P$6, J3.3, K1.P$2, K2.P$2, R8.1, R10.1, U$1.P$33 (GND), U$23.2, U$23.4
GPIO0: J2.P$3, U$1.P$3 (GPIO0)
GPIO1: J2.P$2, U$1.P$4 (GPIO1)
GPIO2: J2.P$4, U$1.P$5 (MTMS)
GPIO3: U$1.P$6 (MTDO)
GPIO4: U$1.P$7 (MTCK)
GPIO5: U$1.P$8 (MTDI)
GPIO8: R9.1, U$1.P$10 (GPIO8)
GPIO9: K1.P$1, U$1.P$11 (GPIO9)
GPIO10: J2.P$6, U$1.P$12 (GPIO10)
GPIO11: J2.P$7, U$1.P$13 (GPIO11)
GPIO12: J1.P$2, U$1.P$14 (GPIO12)
GPIO13: J1.P$3, U$1.P$15 (XTAL_32K_P)
GPIO14: J1.P$4, U$1.P$16 (XTAL_32K_N)
GPIO22: J2.P$5, R6.2, R7.2
GPIO22_1: R7.1, U$1.P$21 (GPIO22)
GPIO25: LED1.P$1, U$1.P$24 (GPIO25)
unnamed: C13.1, R4.1, R5.2
unnamed: R3.1, U$1.P$23 (U0TXD)
unnamed: C10.1, L1.2, U$23.3
unnamed: C9.1, U$1.P$28 (XTAL_N), U$23.1
unnamed: LED2.P$2, R8.2
unnamed: LED1.P$2, R10.2
unnamed: R4.2, U$19.P$1
unnamed: L1.1, U$1.P$29 (XTAL_P)
P$18: R1.1, U$1.P$18 (VBAT)
U1RXD: J1.P$1, U$1.P$22 (U0RXD)
U1TXD: J2.P$1, R3.2
USB_D+: J3.2, U$1.P$26 (GPIO27)
USB_D-: J3.1, U$1.P$25 (GPIO26)
VDD3V3: C1.2, C2.2, C3.2, C4.2, C5.2, C6.2, C7.2, C8.2, C11.2, J1.P$5, LED2.P$1, R1.2, R2.2, R9.2, U$1.P$1 (VDD3P3), U$1.P$2 (VDD3P3_1), U$1.P$9 (VDDPST1), U$1.P$19 (VDDA_PMU), U$1.P$20 (VDDPST2), U$1.P$27 (VDD3P3_2), U$1.P$30 (VDD3P3_3), U$1.P$31 (VDD3P3_4)

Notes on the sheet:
3V3
GPIO
EN SET
boot&reset
ELECROW
Wireless Module ESP32-H2

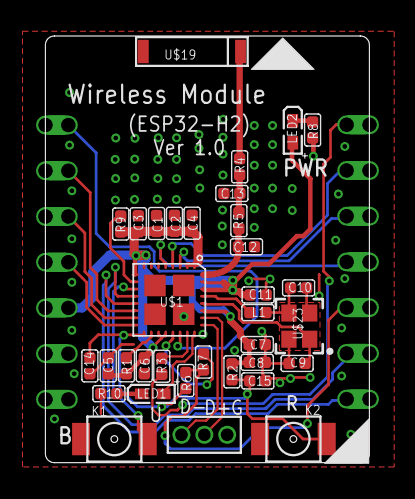
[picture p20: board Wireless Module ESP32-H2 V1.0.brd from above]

Board: 2 copper layers, 18.0 x 23.7 mm, 36 parts (0 on the bottom side), 30 nets.

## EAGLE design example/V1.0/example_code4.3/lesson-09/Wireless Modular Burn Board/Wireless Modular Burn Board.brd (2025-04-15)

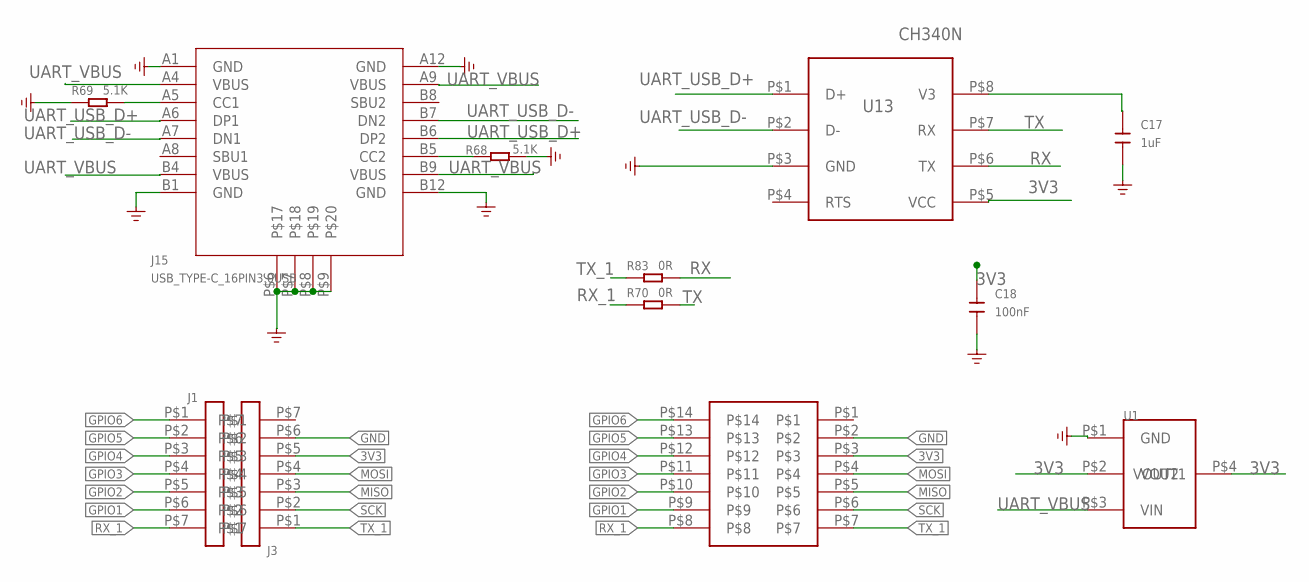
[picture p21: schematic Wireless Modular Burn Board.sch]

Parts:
C17: 1uF; 0603
C18: 100nF; 0603
J1, J3: 2.54MM-7P
J2: SMT-2.54MM-7P
J15: USB_TYPE-C_16PIN3.0USB; KEVIN_3.0TYPEC-SMD
R68, R69: 5.1K; DISCRETE_R0603
R70, R83: 0R; DISCRETE_R0603
U1: AMS1117-3V3; SOT-223
U13: CH340N; SOP8

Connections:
3V3: C18.2, J2.P$3, J3.P$5, U1.P$2 (VOUT1), U1.P$4 (VOUT2), U13.P$5 (VCC)
GND: C17.1, C18.1, J2.P$2, J3.P$6, J15.A1 (GND), J15.A12 (GND), J15.B1 (GND), J15.B12 (GND), J15.P$6, J15.P$7, J15.P$8, J15.P$9, R68.2, R69.1, U1.P$1 (GND), U13.P$3 (GND)
GPIO1: J1.P$6, J2.P$9
GPIO2: J1.P$5, J2.P$10
GPIO3: J1.P$4, J2.P$11
GPIO4: J1.P$3, J2.P$12
GPIO5: J1.P$2, J2.P$13
GPIO6: J1.P$1, J2.P$14
MISO: J2.P$5, J3.P$3
MOSI: J2.P$4, J3.P$4
unnamed: J15.B5 (CC2), R68.1
unnamed: J15.A5 (CC1), R69.2
unnamed: C17.2, U13.P$8 (V3)
RX: R83.2, U13.P$6 (TX)
RX_1: J1.P$7, J2.P$8, R70.1
SCK: J2.P$6, J3.P$2
TX: R70.2, U13.P$7 (RX)
TX_1: J2.P$7, J3.P$1, R83.1
UART_USB_D+: J15.A6 (DP1), J15.B6 (DP2), U13.P$1 (D+)
UART_USB_D-: J15.A7 (DN1), J15.B7 (DN2), U13.P$2 (D-)
UART_VBUS: J15.A4 (VBUS), J15.A9 (VBUS), J15.B4 (VBUS), J15.B9 (VBUS), U1.P$3 (VIN)


Board: 2 copper layers, 30.0 x 29.1 mm, 12 parts (0 on the bottom side), 21 nets.

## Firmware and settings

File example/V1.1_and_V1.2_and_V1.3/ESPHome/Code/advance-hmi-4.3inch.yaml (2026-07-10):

# Board: Generic ESP32-S3 Board (Generic)
# Definition: definitions/boards/generic-esp32s3/manifest.yaml

esphome:
  name: advance-hmi-4.3inch
  friendly_name: Advance-HMI-4.3inch
  platformio_options:
    build_flags: "-DBOARD_HAS_PSRAM"
    board_build.esp-idf.memory_type: qio_opi
    board_build.flash_mode: dio
  on_boot:
    priority: 600.0
    then:
      - lambda: |-
          uint8_t cmd[1] = { 0 };
          id(bus_a).write(0x30, cmd, 1);  
          
esp32:
  board: esp32-s3-devkitc-1
  framework:
    type: esp-idf
    sdkconfig_options:
      CONFIG_ESP32S3_DEFAULT_CPU_FREQ_240: y
      CONFIG_ESP32S3_DATA_CACHE_64KB: y
      CONFIG_SPIRAM_FETCH_INSTRUCTIONS: y
      CONFIG_SPIRAM_RODATA: y

psram:
  mode: octal
  speed: 80MHz 
  
logger:

api:
  encryption:
    key: "14bI+bVdoDi1ta6bYCZDu9F6KQNWrZNOWBloFqbDmVA="

ota:
  - platform: esphome
    password: "2f9d5f76dae10035c0774cf82aedd357"

wifi:
  ssid: !secret wifi_ssid
  password: !secret wifi_password
  ap:
    ssid: Advance-HMI-43inch Fallback Hotspot
    password: "AbsADRw3NPEn"

captive_portal:

switch:
  - platform: gpio
    pin: GPIO19
    name: "LED"
    id: led_output
    on_turn_on:
      # Switch bulb diagram
      - lvgl.image.update:
          id: lvgl_light
          src: light_on
      # Switch the status label text to ON
      - lvgl.label.update:
          id: label_light_state
          text: "ON"
    on_turn_off:
      # Switch bulb diagram
      - lvgl.image.update:
          id: lvgl_light
          src: light_off
      # Switch the status label text to OFF
      - lvgl.label.update:
          id: label_light_state
          text: "OFF"
          

  - platform: template
    name: "Backlight Power"
    id: backlight_switch
    turn_on_action:
      - lambda: |-
          uint8_t cmd[1] = { 0 };
          id(bus_a).write(0x30, cmd, 1);
    turn_off_action:
      - lambda: |-
          uint8_t cmd[1] = { 245 };
          id(bus_a).write(0x30, cmd, 1);

image:
  - file: "small_temp.png"
    id: small_temp
    resize: 200x200
    type: RGB565
  - file: "small_hum.png"
    id: small_hum
    resize: 200x200
    type: RGB565
  - file: "small_logo.png"
    id: small_logo
    resize: 200x200
    type: RGB565
    transparency: chroma_key
  - file: "light.png"
    id: light_on
    resize: 200x200
    type: RGB565
  - file: "no_light.png"
    id: light_off
    resize: 200x200
    type: RGB565

i2c:
  sda: 15
  scl: 16
  scan: true
  id: bus_a

sensor:
  - platform: aht10
    variant: AHT20
    temperature:
      name: "Room Temperature"
      id: room_temp
      unit_of_measurement: "°C"
      accuracy_decimals: 1
    humidity:
      name: "Room Humidity"
      id: room_hum
      unit_of_measurement: "%"
      accuracy_decimals: 1
    update_interval: 1s

display:
  - platform: rpi_dpi_rgb
    id: main_display
    color_order: RGB
    invert_colors: true
    update_interval: never
    auto_clear_enabled: false
    dimensions:
      width: 800
      height: 480
    de_pin: 42
    hsync_pin: 40
    vsync_pin: 41
    pclk_pin: 39
    pclk_frequency: 20MHz
    hsync_pulse_width: 4
    hsync_front_porch: 8
    hsync_back_porch: 8
    vsync_pulse_width: 4
    vsync_front_porch: 8
    vsync_back_porch: 8
    data_pins:
      red:
        - 7
        - 17
        - 18
        - 3
        - 46
      green:
        - 9
        - 10
        - 11
        - 12
        - 13
        - 14
      blue:
        - 21
        - 47
        - 48
        - 45
        - 38

time:
  - platform: homeassistant
    id: time_comp

lvgl:
  log_level: INFO
  color_depth: 16
  bg_color: 0xFFFFFF
  text_font: montserrat_26
  widgets:
    - image:
        id: lvgl_logo
        src: small_logo
        x: 300
        y: 20
    - image:
        id: lvgl_temp
        src: small_temp
        x: 150
        y: 250
    - image:
        id: lvgl_hum
        src: small_hum
        x: 400
        y: 250
    - image:
        id: lvgl_light
        src: light_off    # Default 'Turn off lights' image
        x: 650            # You can adjust the position by yourself
        y: 250
    - label:
        id: label_temp
        x: 90
        y: 350
        text: "Temp: --°C"
    - label:
        id: label_hum
        x: 350
        y: 350
        text: "Humi: --%"
    - label:
        id: label_light_state
        x: 650
        y: 350
        text: "OFF"

interval:
  - interval: 1s
    then:
      - lambda: |-
          char temp_str[20];
          char hum_str[20];
          snprintf(temp_str, sizeof(temp_str), "Temp: %.1f°C", id(room_temp).state);
          snprintf(hum_str, sizeof(hum_str), "Humi: %.1f%%", id(room_hum).state);
          lv_label_set_text(id(label_temp), temp_str);
          lv_label_set_text(id(label_hum), hum_str);        

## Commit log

2026-04-22 sync example/V1.1V1.2
    [code-format.cfg, partitions.csv]
2026-06-15 rename folders
    [code-format.cfg, partitions.csv]
2026-08-03 更新代码 2026-08-03 14:59
    [code-format.cfg, partitions.csv]
